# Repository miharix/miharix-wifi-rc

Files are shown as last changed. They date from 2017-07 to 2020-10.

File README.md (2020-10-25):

# Miharix WiFi RC
[SLO](#slo) / [DE](#de) / [ENG](#eng)

PCB and Firmware for **super cheap RC control over WiFi (Smart phone, Tablet, PC, ...)**

 I was a teacher(10 years) and wanted to make RC more affordable and be able to build something RC in class
 (yes all kids in a regular class and for grade - budget: 15€/kid)

So I made a this simple and very cheap module that enables to control standard RC components using WiFi and Phone/Tablet/PC
BUT the main difference to existing one is,
**IT DOESN'T NEED a special software**, only a web-browser and it **DOESN'T need an internet connection**.
*(you don't want to install something to 100 kids phones, and not all phones are the same! paid data traffic no go!)
And to reprogram it(new sw version / first steps to robotics) you need an inexpensive WittyCloud(~2€).*

The module was used in my class, 3 other teachers, and in 2 modellmaking summer camps. Totally around 300 kids*

Published in [elektor Elektor magazine11/2018](https://www.elektormagazine.com/index.php/magazine/elektor-52/42095)  on page 82

Published in magazine [TIM 4/2018](https://plus.si.cobiss.net/opac7/bib/40185093)  on page 24-27

 

* ***I stil have some asembled & programmed modules and also bare PCB-s left.
If you are interested, let me know [m.....x@gmail.com](https://mailhide.io/e/yFDyB)***

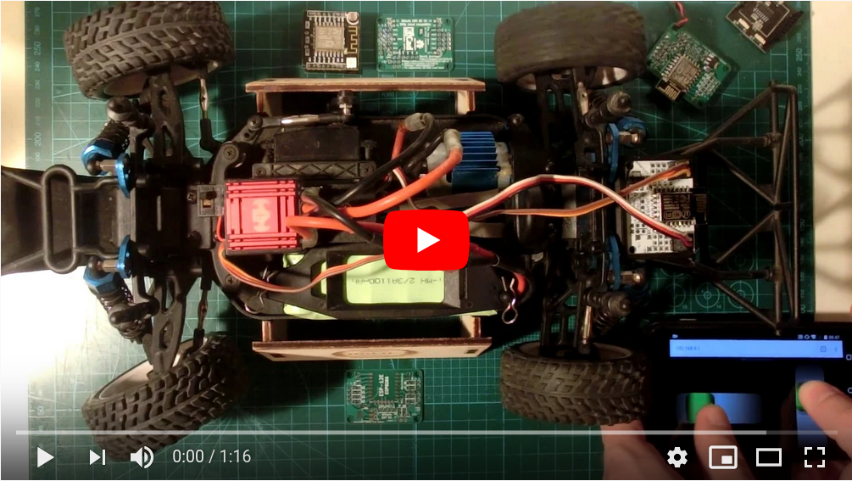
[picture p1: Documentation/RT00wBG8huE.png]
(https://www.youtube.com/watch?v=RT00wBG8huE)


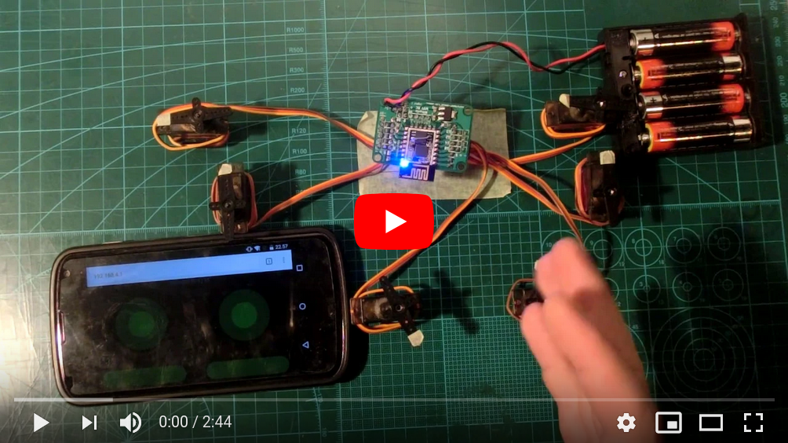
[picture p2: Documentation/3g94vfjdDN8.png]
(https://www.youtube.com/watch?v=3g94vfjdDN8)


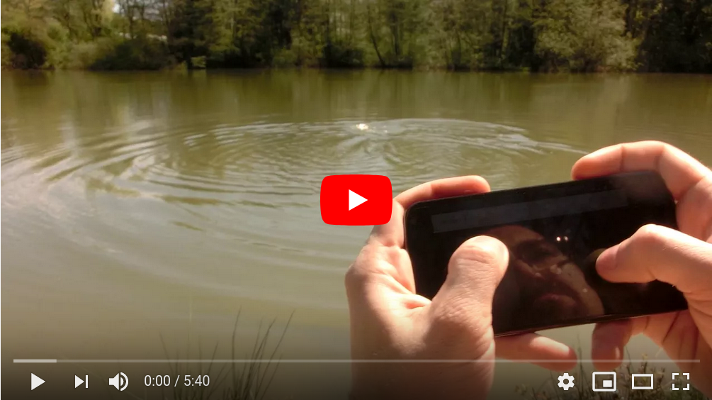
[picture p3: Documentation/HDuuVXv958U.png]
(https://www.youtube.com/watch?v=HDuuVXv958U)


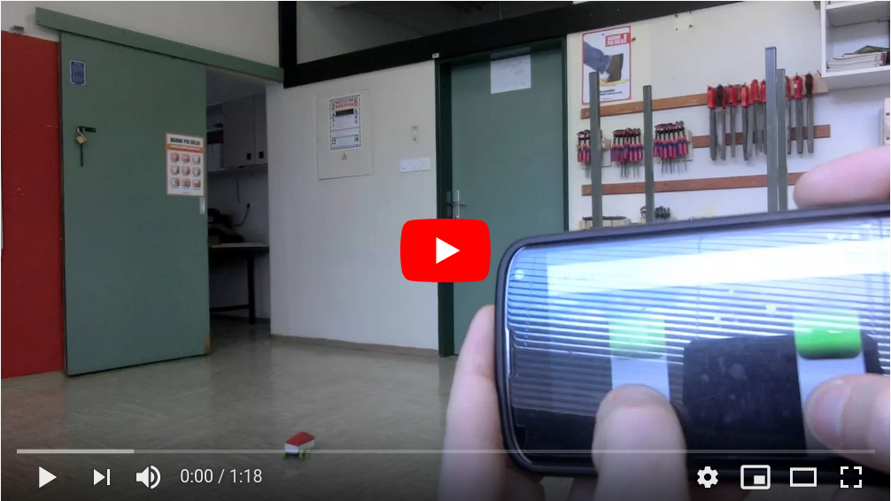
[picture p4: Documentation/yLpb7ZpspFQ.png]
(https://www.youtube.com/watch?v=yLpb7ZpspFQ)


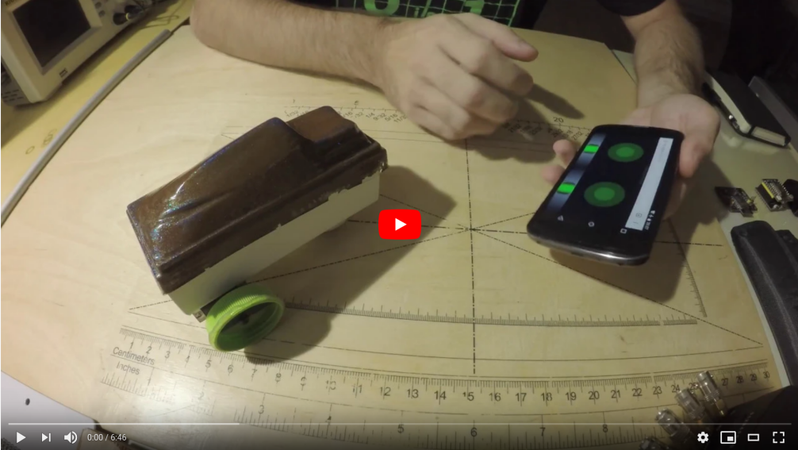
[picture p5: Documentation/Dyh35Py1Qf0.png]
(https://www.youtube.com/watch?v=Dyh35Py1Qf0)


---

#### [ENG]

PCB and Example Software for making super cheap RC control over WiFi (mobile phone,tablet,...)

If you like this project, you are welcome to support this and my further projects over https://paypal.me/miharix

What is in the folders:

* **3Dp** - simple 3Dp case
* **Arduino** - *source code examples for programming the module*
* **DIY** - *pdf for making PCB DIY at home*
* **Documentation** - *shematic and dimensions*
* **Gerber** - *files for a PCB factory*
* **Render** - *3D render of PCB*
* **Python** - *source code examples for PC control*

**For building you also need:**

* 1x ESP-12E *(ESP8266)*
* 1x MCP1755ST-3302E 3,3V 300mA
* 2x 10K SMD805 (10 kilo ohm)
* 2x 1µF SMD805 (1 mikro Farad)
* optional 3-44 pin header male one line breakable raster 2,54mm

For easy programming use "Witty cloud"

Ground range test cca 90m
[(5s before car stops, the signal is lost)](https://youtu.be/WoqIe_oOWTM)

Todo List:

* Testing on more devices
* Range test using external antena, router...
* Manual(video?) how to build, programming, configure...
* ~~(6 servo demo)Expo~~
* (6 servo demo)Disable nipple retun to center for individual axes 
* (6 servo demo)Simultan button(channel 5&6) press and nipple usage
* ...

---

#### [DE]

Schaltung und  Programmierbeispiele um eine super-billige Modellbaufernbedienung über WiFi (Smartphone, Tablett,...) zu bauen.

Wen ihnen die Schaltung nutzbar ist, können Sie die Weiterentwicklung diesen und zukünftige Projekte mit kleiner Donation über https://paypal.me/miharix unterstützen.

Was sich in der Unterordner befindet:

* **3Dp** - einfaches 3Dp Gehäuse
* **Arduino** - *Programmierbeispiele um den Modul zu programmieren*
* **DIY** - *pdf um die Schaltung Zuhause selber nachzumachen*
* **Documentation** - *Schema der Schaltung und Maßnahmen*
* **Gerber** - *Dateien für PCB Hersteller*
* **Render** - *3D Rander von PCB*
* **Python** - *Programmierbeispiele um Mudil mit PC zu steuern*

**Um es zu bauen braucht man noch:**

* 1x ESP-12E *(ESP8266)*
* 1x MCP1755ST-3302E 3,3V 300mA
* 2x 10K SMD805 (10 kilo ohm)
* 2x 1µF SMD805 (1 mikro Farad)
* Optional 3-44 Stiftleisten Raster 2,54mm

Um es es ganz einfach zu Programmieren ist die "Witty cloud" als Programmierer gerät vorgesehen. 

Getestete Reichweite am Boden hohe cca 80m
 [(5s bevor der Auto anhielt wurde der Signal abgebrochen)](https://youtu.be/WoqIe_oOWTM)

Noch zu tun:

* Test auf Kompatibilität mit noch mehreren Geraten
* Test der Reichweite bei Gebrauch einer externer Antenne, Routers...
* Anleitung(Video?) wie man es baut, programmiert, konfiguriert...
* ~~(6 servo demo)Expo~~
* (6 servo demo)Ausschalten in die Mitte zurück springen beliebiges Knüppel  
* (6 servo demo)Gleichzeitige Aktivierung der Knöpfe 5&6 und Knüppel Bewegung.
* ...

---

#### [SLO]

Vezje in programski primeri za izdelavo super poceni RV preko WiFi (pametni telefon,tablica,...)

V kolikor vam vezje koristi, lahko podprete razvoj tega ter bodočih projektov s donacijo preko: https://paypal.me/miharix

Kaj se nahaja v mapah:

* **3Dp** - preprosto ohišje za 3Dp
* **Arduino** - *programski primeri za programiranje modula*
* **DIY** - *pdf za izdelavo tiskanega vezja v domači delavnici*
* **Documentation** - *shema vezave in mere*
* **Gerber** - *datoteke za proizvajalca vezij*
* **Render** - *3D izris vezja*
* **Python** - *primer kode za krmiljenje iz računalnika*

**Za  izdelavo še potrebujete:**

* 1x ESP-12E *(ESP8266)*
* 1x MCP1755ST-3302E 3,3V 300mA
* 2x 10K SMD805 (10 kilo ohm)
* 2x 1µF SMD805 (1 mikro Farad)
* opcijsko 3-44 letev moška enoredna lomljiva raster 2,54mm

Za preprosto programiranje predvidena uporaba "Witty cloud"

Testiran domet na zemlji približno 80m
 [(5s preden se avto ustavi na tem posnetku, se je zgubil signal)](https://youtu.be/WoqIe_oOWTM)

Za naredit:

* Testirat na čim več napravah
* Test dometa pri uporabi zunanje antene, ruterja...
* Navodila(video?) kako izdelat, programirat, nastavljat...
* ~~(6 servo demo)Expo~~
* (6 servo demo)Izklop samodejnega povratka ročice poljubne osi v središče
* (6 servo demo)Sočasno aktivianje gumba za 5&6 med premikanjem ročic
* ...

---

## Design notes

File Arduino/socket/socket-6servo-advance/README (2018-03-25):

* 6 servo support
* easy configurable
	* each servo configurable:
		*	Trim center
		*	Max position
		*	Min position
		*	Fail position
		*	Expo rate
		*	Rate speed
		*	Reverse
	* Fail save timeout
	* 9 different control designs
	* RC model name
	* Access Point(AP) mode or connect to existing WiFi
	* SSID
	* Password
* includes possibility to hard reset to "factory" settings
* in case of wrong SSID or Password in non AP mode after 5 min triggers reset to "factory" settings
* "factory" settings SSID includes MAC

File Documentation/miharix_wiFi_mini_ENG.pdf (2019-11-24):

# Miharix WiFi RC

# Control your RC models over WiFi (e.g.: smartphone, tablet, laptop...) Without a need for a special App Without a need for Internet or Mobile data

# WiFi Antenna

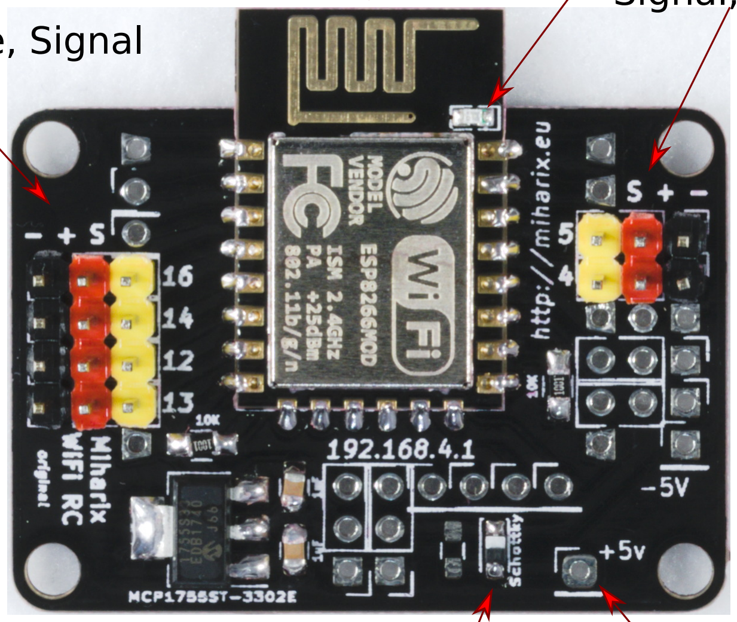
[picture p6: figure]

## Servo 1 Servo 3 Servo 5 Servo 6

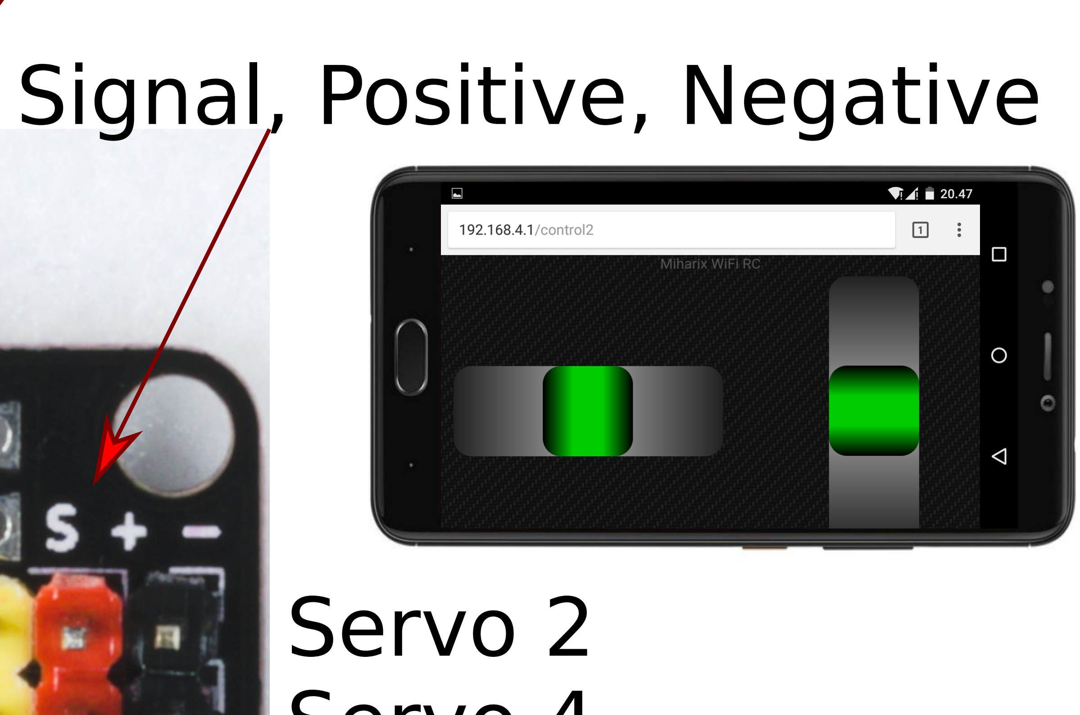
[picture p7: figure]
Servo 2; Signal, Positive, Negative

## Servo 4

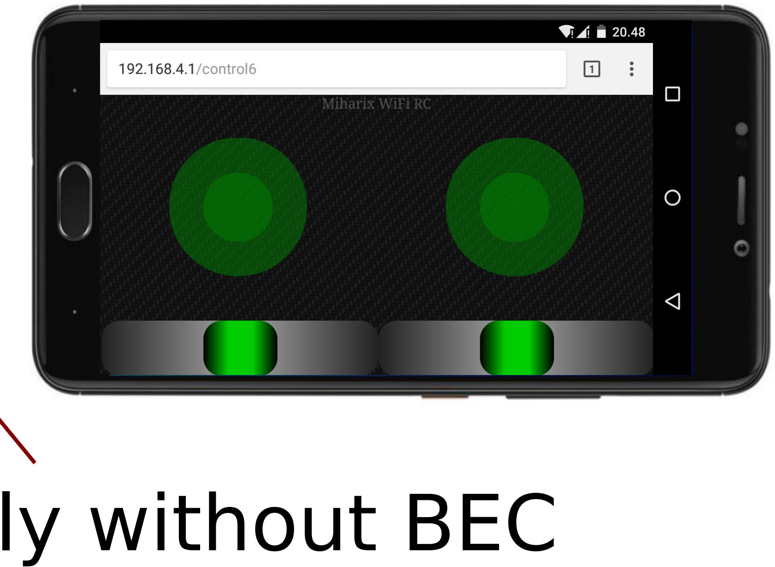
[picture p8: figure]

## Optional: Power supply without BEC

Voltage should not exceed max servo voltage for used servo motors

## Most of the time 5V (4xAA)

Wrong polarity protection for optional power supply

## Negative, Positive, Signal

Usage in short:
1. Turn on power supply for module
2. On mobile device (e.g. smartphone) turn on WiFi

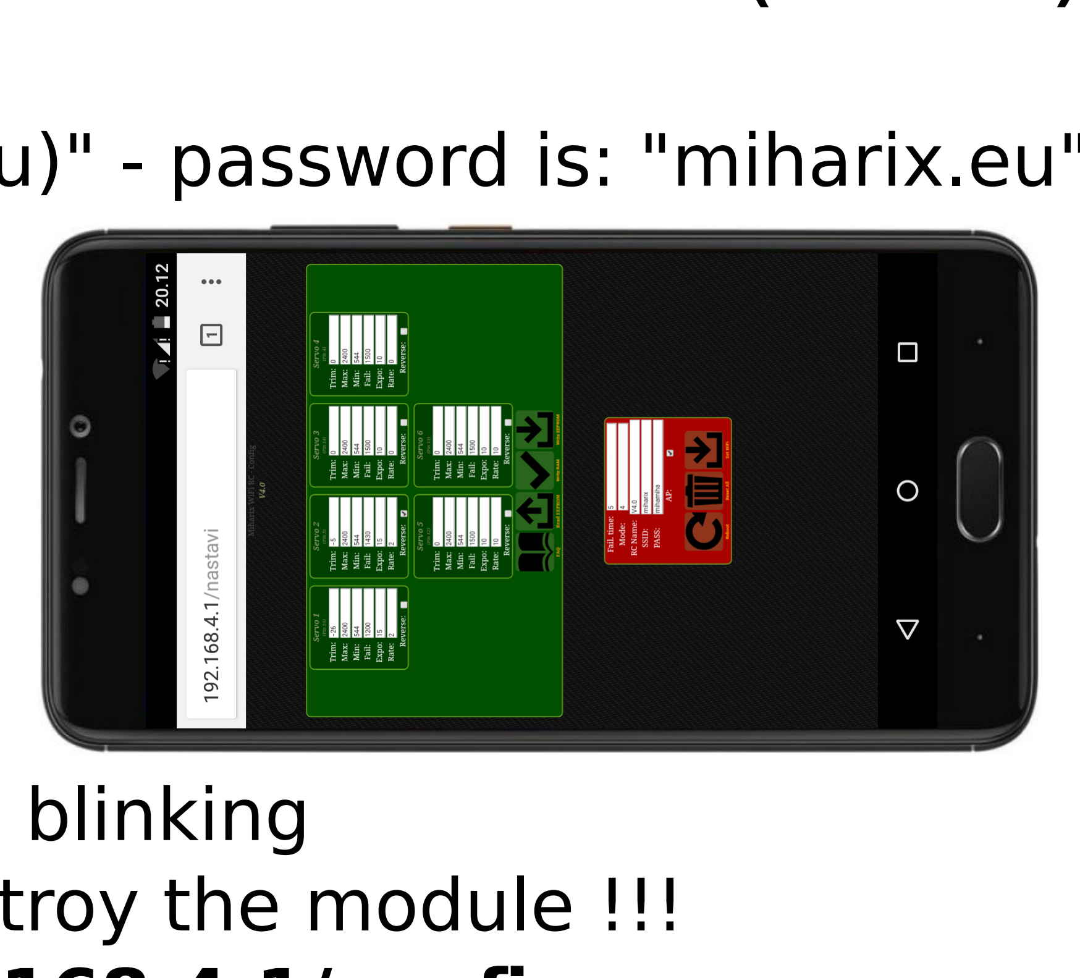
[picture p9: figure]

3. Connect to WiFi, who's names is made of modules MAC and ends on "(miharix.eu)" - password is: "miharix.eu"
4. Open your browser, the best if it's Chrome
5. In URL row type web address "http://192.168.4.1"
6. Follow manual on the website

FAQ:
I forgot my password - Find on the back side marked GPIO0 (under Servo4)
You need to short the left signal GPIO0 and right outer - (minus) till the LED stops blinking
WARNING do not short any of inner(yellow/signal) whit middle(red) pin, it will destroy the module !!! I have set up the module but I would like to change settings: http://192.168.4.1/config
(also possible /nastavi /uredi, /administrator, /admin, /setup, /root)
Do I now have Internet wherever I am? :-) No, WiFi doesn't automatically mean internet
Do I need internet for controlling my model? No, only a device, that supports WiFi and has a browser Can I connect model to existing WiFi? Yes, in settings disable AP and insert networks SSID and password I typed wrong password for existing WiFi. Leave on for 5min, module will factory reset automatically. What's maximum range? Tested cca. 80-90m (90-100 Yard)
What is that "Mode:" ? Module ha multiple interfaces for controlling.
You can try them fast on http://192.168.4.1/control1 (next is control2, control3 ...)

LED - status indicator states:
On - fail-save
Off - connection is active
Progressive faster blinking for 1min - Sure to do a factory reset?

For Each Servo you can set
Reverse, Trim, Max, Min, Fail-save, Expo, Rate

Able to set custom WiFi name and password

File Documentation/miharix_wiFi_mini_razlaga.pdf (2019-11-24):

# Miharix WiFi RC

# Krmiljenje modelarskih modelov preko WiFi (npr: telefon, tablica, prenosnik...) Brez potrebe po namenski aplikaciji Brez potrebe po Internetu ali Mobilnih podatkih

# WiFi Antena

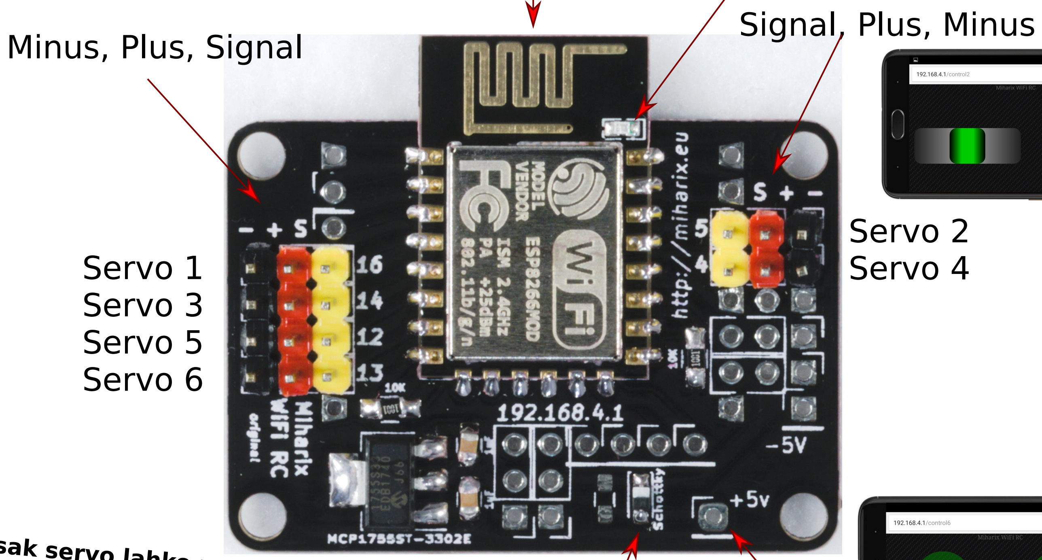
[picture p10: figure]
Signal, Plus, Minus Minus, Plus, Signal

## Servo 1 Servo 3 Servo 5 Servo 6

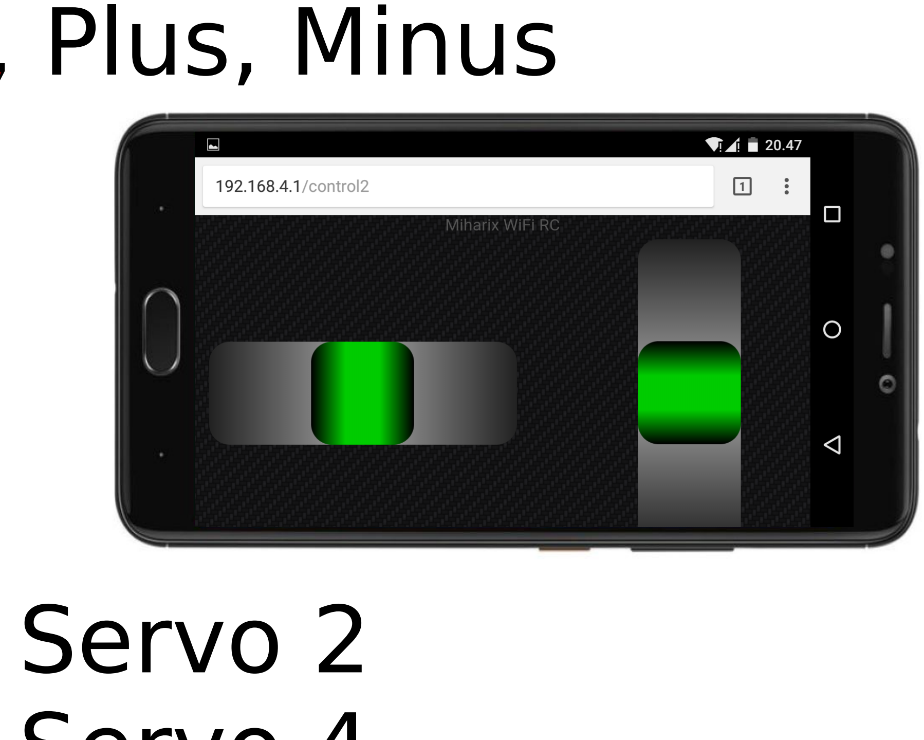
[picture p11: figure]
Servo 2

## Servo 4

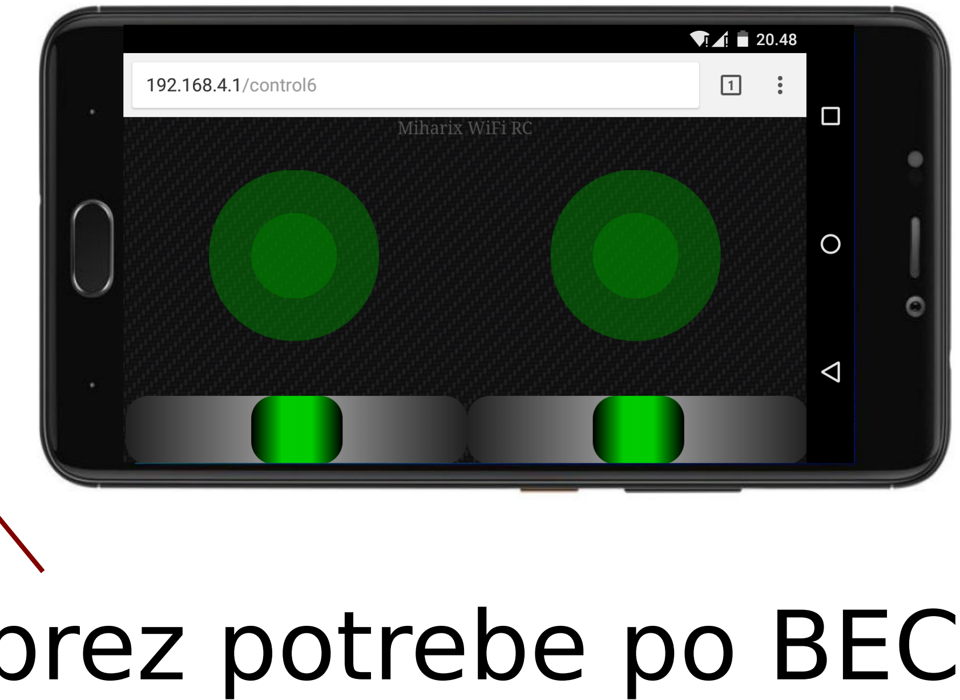
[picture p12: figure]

## Opcijsko: Napajanje brez potrebe po BEC

Napetost ne sme preseči maksimalne napajalne napetosti uporalbjenih servo motorjev

## Najpogosteje 5V (4xAA)

Zaščita pred napačno polariteto opcijskega napajanja

Uporaba na kratko:
1. Vklopi napajanje modula
2. Na mobilni napravi(npr telefon) vklopi WiF

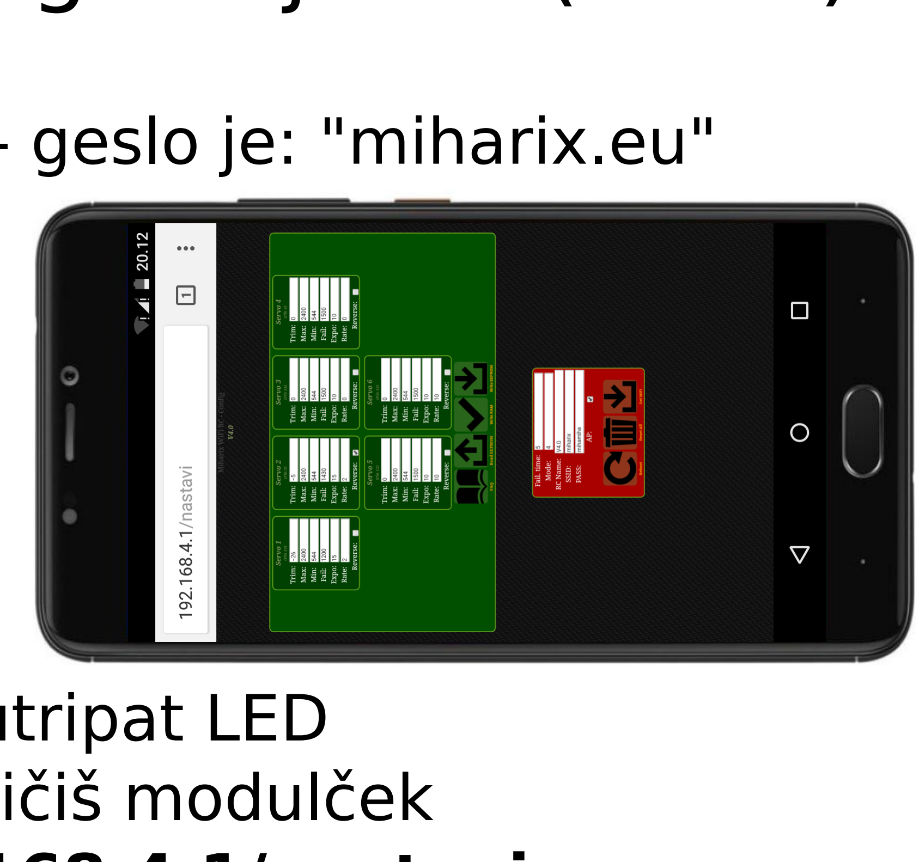
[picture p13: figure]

3. poveži se na WiFi, ki je sestavljen iz MAC modula ter se konča z "(miharix.eu)" - geslo je: "miharix.eu"
4. Odpri brskalnik, najbolje Chrome
5. V URL vrstico vtipkaj spletni naslov "http://192.168.4.1"
6. Sledi navodilom na spletni strani

FAQ:
Pozabil sem geslo - Poišči na zadnji strani označen GPIO0 (takoj pod Servo4)
Skleniti moraš skrajno notranji GPIO0 ter zunanji desni - (minus) dokler ne neha utripat LED POZOR ne smeš sklenit nobenega rumenega(notranji) z rdečim(sredina), sicer uničiš modulček Nastavil sem modul in bi rad naknadno spremnil nastavitve: http://192.168.4.1/nastavi (lahko tudi /uredi, /administrator, /admin, /config, /setup, /root)
A imam sedaj Internet kjer koli sem? :-) Ne, WiFi ne pomeni avtomatično internet
Rabim internet za upravljanje modela? Ne, le napravo ki podpira WiFi ter ima brskalnik
Lahko priključim model na obstoječi WiFi? Da, onemogoči v nastavitvah AP, vnesi SSID in geslo omrežja Vtipkal sem napačsno geslo za obstoječi WiFi. Pusti prižgano 5min, modul se bo ponastavil sam Kakšen je domet? Testirano cca 80-90m
Kaj je to "Mode:" ? Vmesnik ima več oblik za krmiljenje.
Na hitro jih lahko preizkusiš z http://192.168.4.1/control1 (naslednji je control2, control3 ...)

LED - indikator stanja
Prižgan - failsave
Izklopljen - povezava aktivna
Vedno hitrejše utripanje 1min - Res želiš vse resetirat?

Za vsak servo lahko nastaviš: Reverse, Trim, Max, Min, Failsave, Expo, Rate

Nastavljivo poljubno WiFi ime ter geslo

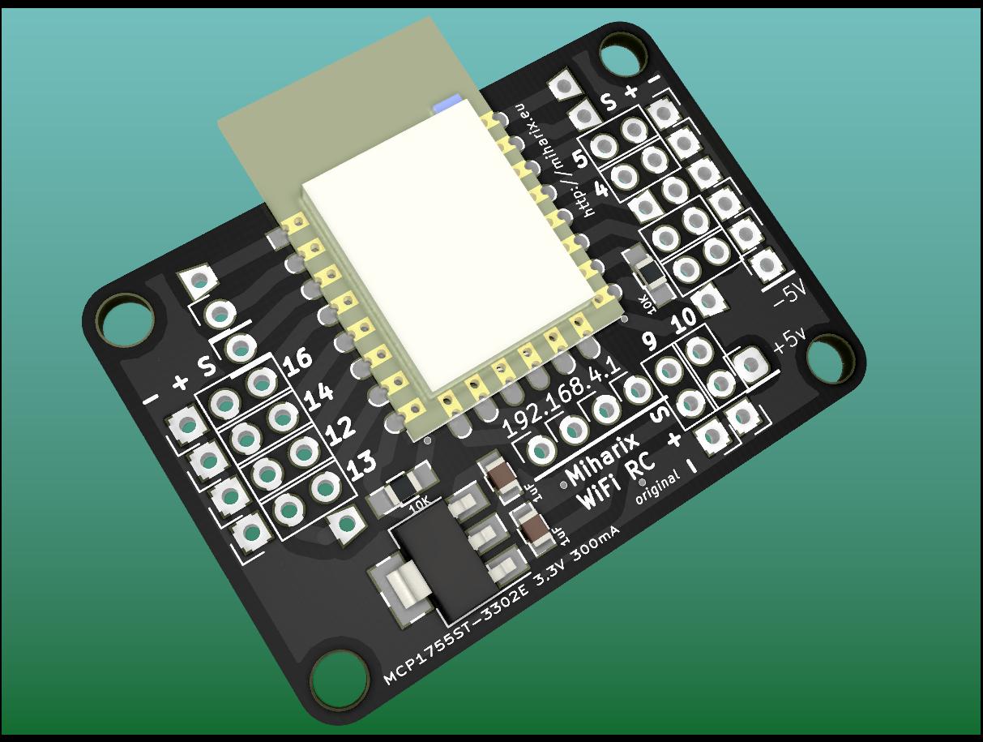
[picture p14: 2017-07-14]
Render/V3/ESP_servo_v3_2.jpg

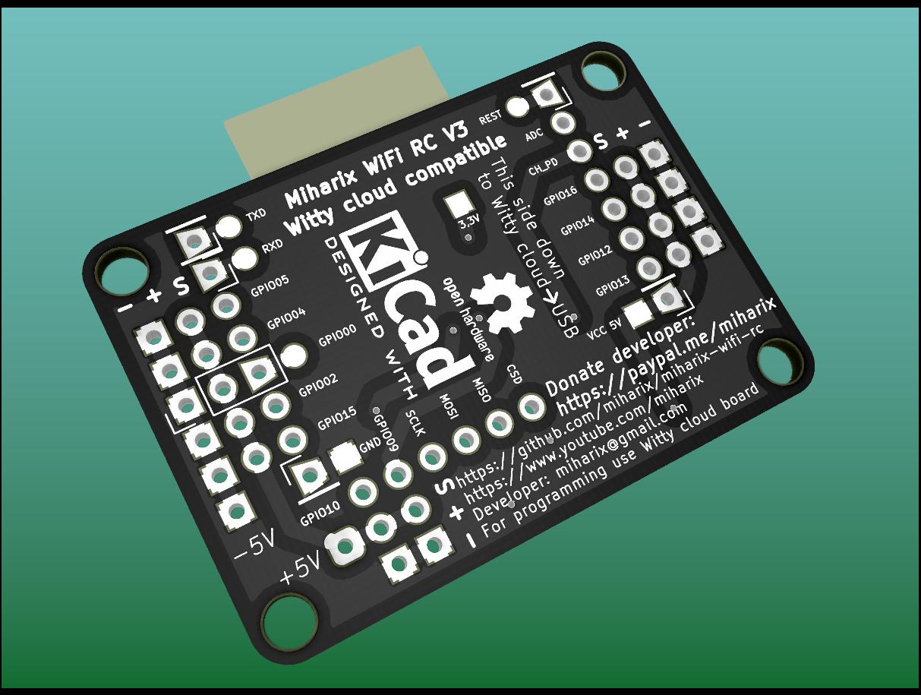
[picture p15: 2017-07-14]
Render/V3/ESP_servo_v3_5.jpg

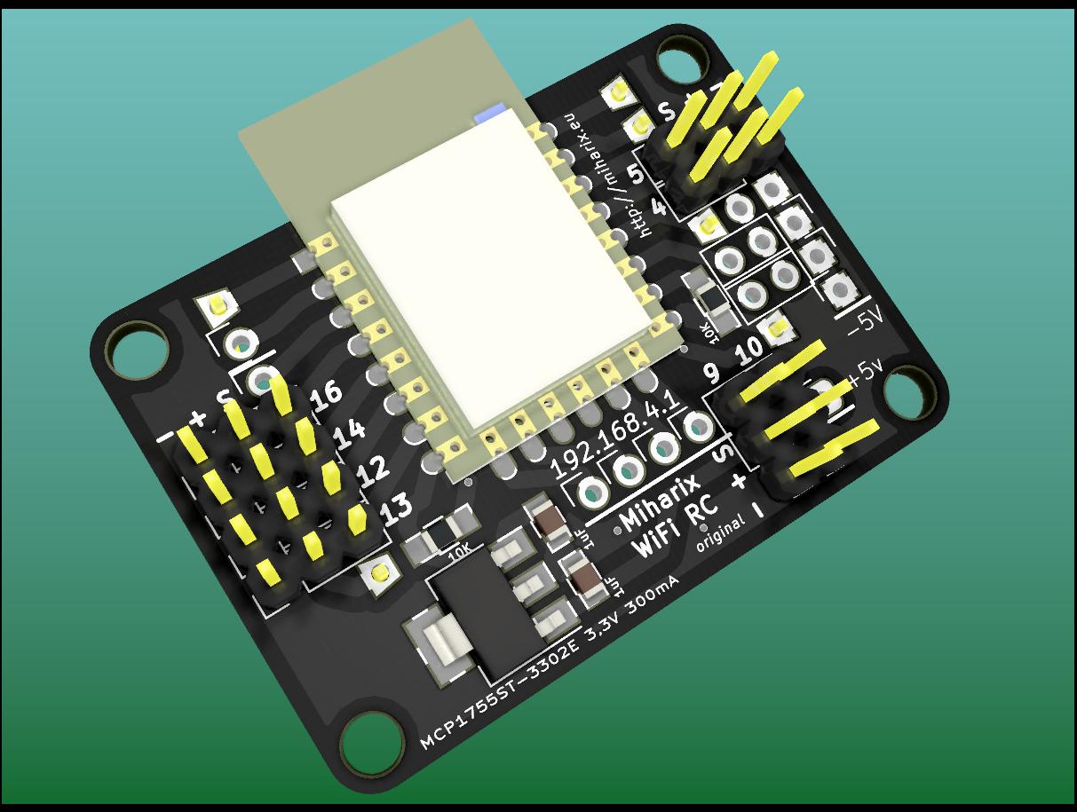
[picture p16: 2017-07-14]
Render/V3/ESP_servo_v3.jpg

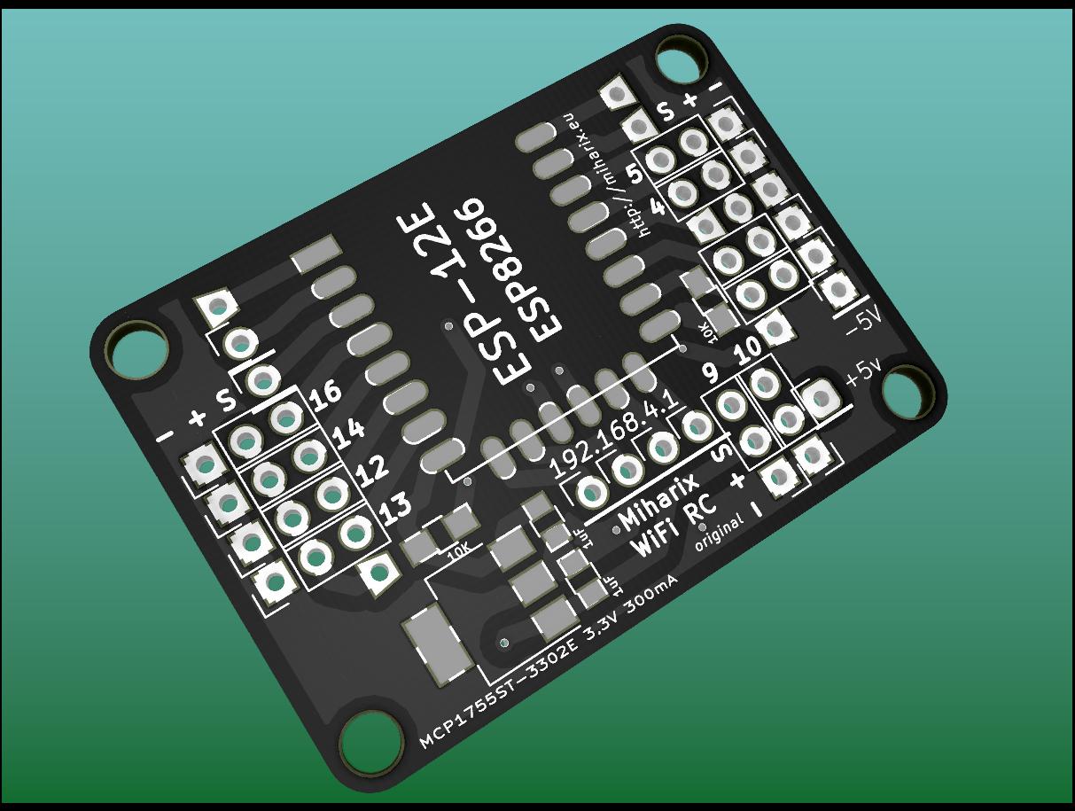
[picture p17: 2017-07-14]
Render/V3/ESP_servo_v3_3.jpg

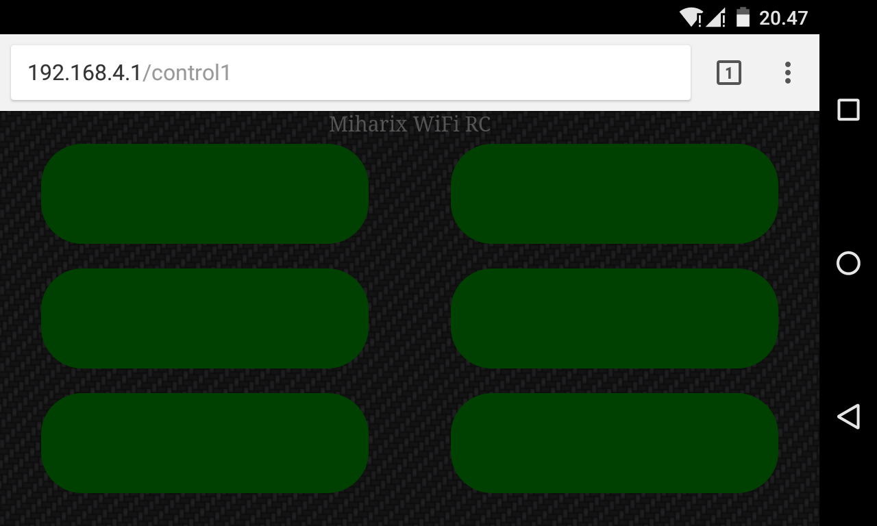
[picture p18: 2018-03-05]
Arduino/socket/socket-6servo-advance/Screenshots/Screenshot_nexus4_CONTROL1.png

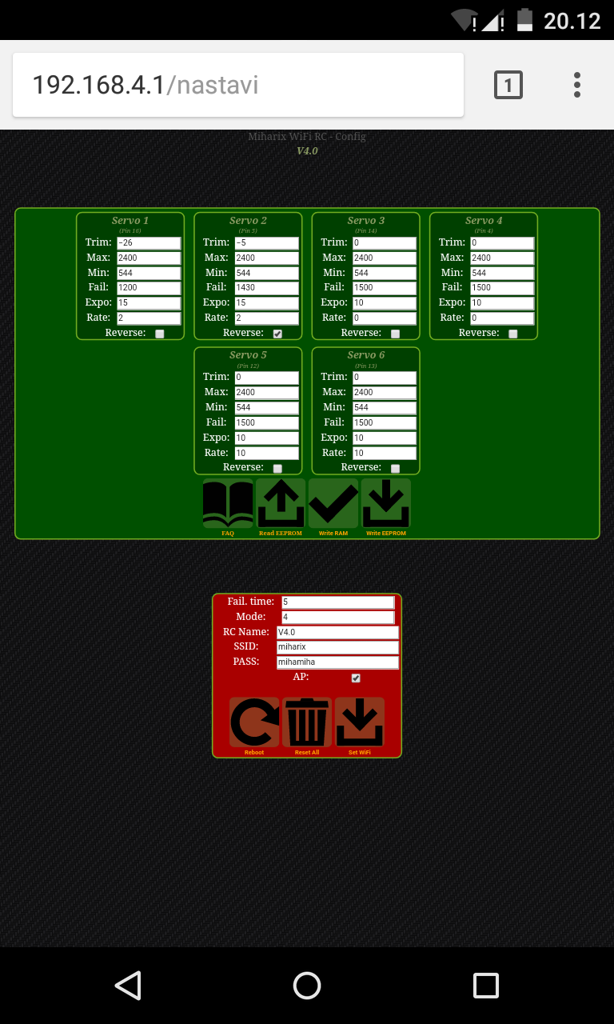
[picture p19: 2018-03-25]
Arduino/socket/socket-6servo-advance/Screenshots/Screenshot_nexus4_CONFIG.png

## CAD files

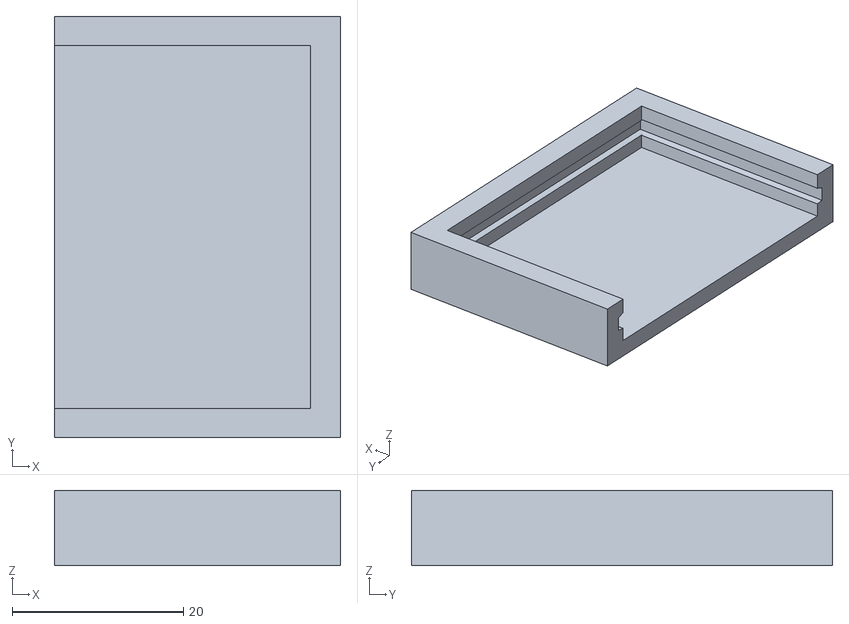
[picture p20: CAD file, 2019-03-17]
3Dp/pcb_protect_v3.stl
33.4 x 49.1 x 8.80

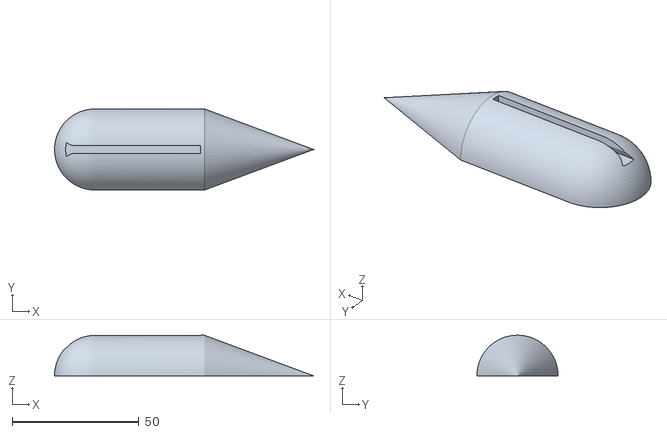
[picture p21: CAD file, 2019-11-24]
model_examples/Sumpi/sumpi.stl
102.0 x 32.0 x 16.0

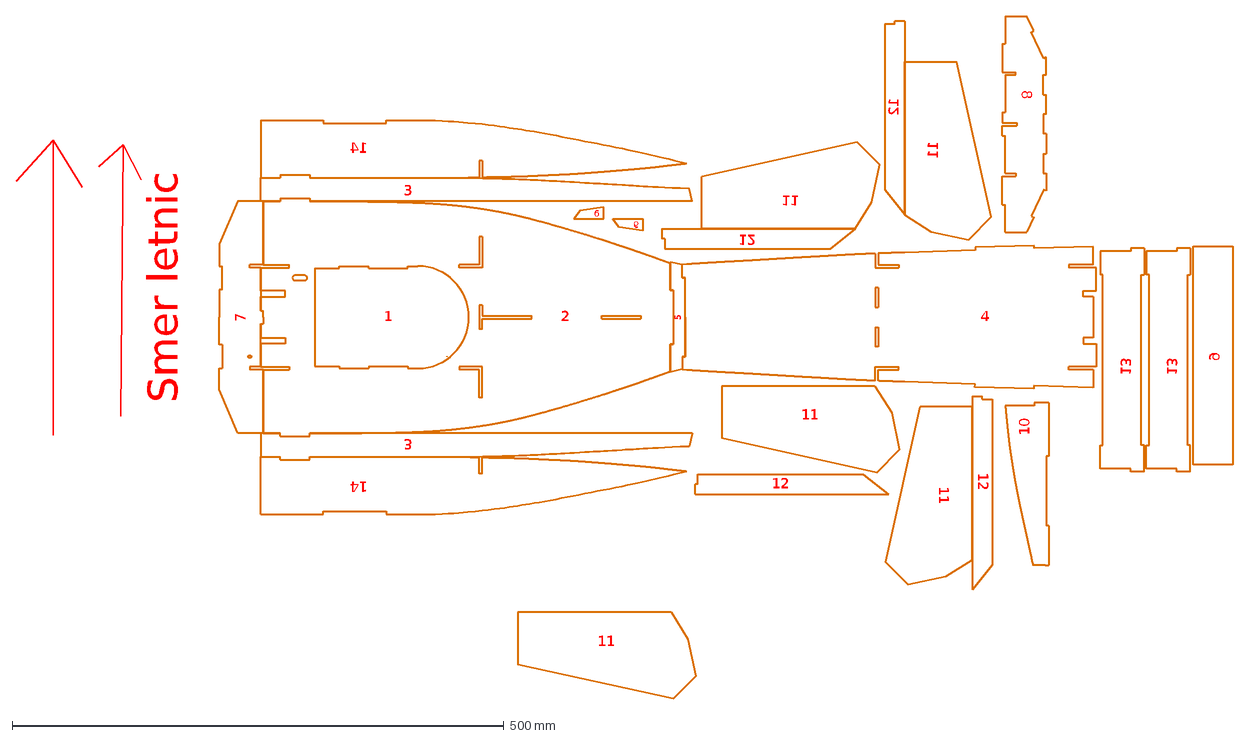
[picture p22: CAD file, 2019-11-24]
model_examples/Sumpi/sumpi_3mm.dxf
6
1
2
7
5
11
3
14
4
12
13
9
Smer letnic
8
10

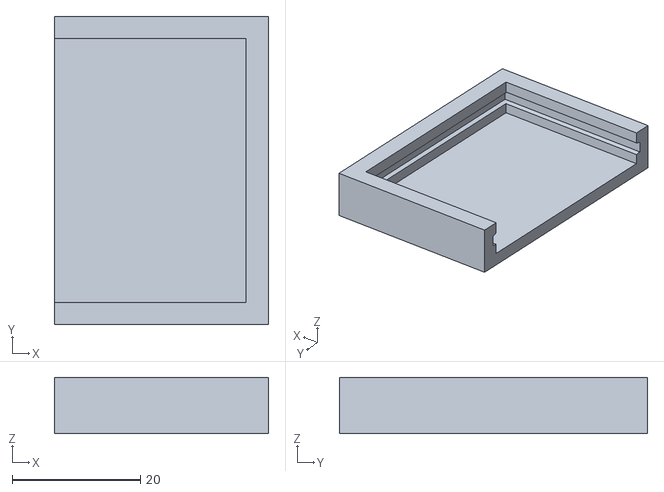
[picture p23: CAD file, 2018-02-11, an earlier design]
3Dp/pcb_protect.stl
33.4 x 48.0 x 8.80

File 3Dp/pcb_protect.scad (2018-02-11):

pcb_height=31;
pcb_width=43.18;
pcb_thick=2;
grove=1;
walls=2.4;
bottom_offset=2;
chamfer_top=0.7;//[0.0:1.0]
chamfer_bottom=0.3;//[0.0:1.0]


difference(){
//box
translate([walls/2+0.1,0,pcb_thick/2+bottom_offset/2]){
cube([pcb_height+walls,pcb_width+walls*2,pcb_thick+walls*2+bottom_offset],center=true);
}

//pcb
color("green")
translate([0,0,pcb_thick/2+bottom_offset]){
cube([pcb_height,pcb_width,pcb_thick],center=true);
}

//grove
color("blue")
translate([-grove/2,0,pcb_thick+walls/2+bottom_offset]){
cube([pcb_height-grove,pcb_width-grove*2,walls+0.01],center=true);
}


//chamfer top
color("red")
translate([-grove/2,0,pcb_thick+walls/2+bottom_offset-0.01]){
linear_extrude(height = walls+0.1, center = true, convexity = 3, scale = chamfer_top){
square(size = [pcb_height, pcb_width], center = true);
}
}

//bottom offset
color("Gray")
translate([-grove/2,0,bottom_offset/2]){
cube([pcb_height-grove,pcb_width-grove*2,bottom_offset+0.01],center=true);
}

//chamfer bottom
color("Purple")
translate([-grove/2,0,bottom_offset/2+0.01]){
mirror([0,0,1]) 
linear_extrude(height = bottom_offset, center = true, convexity = 3, scale = chamfer_bottom){
square(size = [pcb_height, pcb_width], center = true);
}
}

}

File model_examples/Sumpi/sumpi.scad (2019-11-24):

$fn=80;

module trikotnik(stranica,visina){
    polmer=(stranica*sqrt(3))/3;
    translate([visina/2,0,polmer/2])
    rotate([0,-90,0])
    cylinder(h=visina,r=polmer,$fn=3);
}



difference(){

hull(){

/*translate([0,0,0])
rotate([0,90,0])
cylinder(h=43,r=16,center=true);
*/
translate([43,0,0])
rotate([0,90,0])
cylinder(h=43, r1=16, r2=0,center=true);

translate([-43/2,0,0])
sphere(r=16);
}

translate([-10,0,11])
trikotnik(5.5,60);

translate([-10,0,16])
cube([60,3,6],center=true);

translate([10,0,-16])
cube([130,16*2,16*2],center=true);
}

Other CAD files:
model_examples/MobiRobi/nacrt.dxf
model_examples/Sumpi/sumpi.dxf

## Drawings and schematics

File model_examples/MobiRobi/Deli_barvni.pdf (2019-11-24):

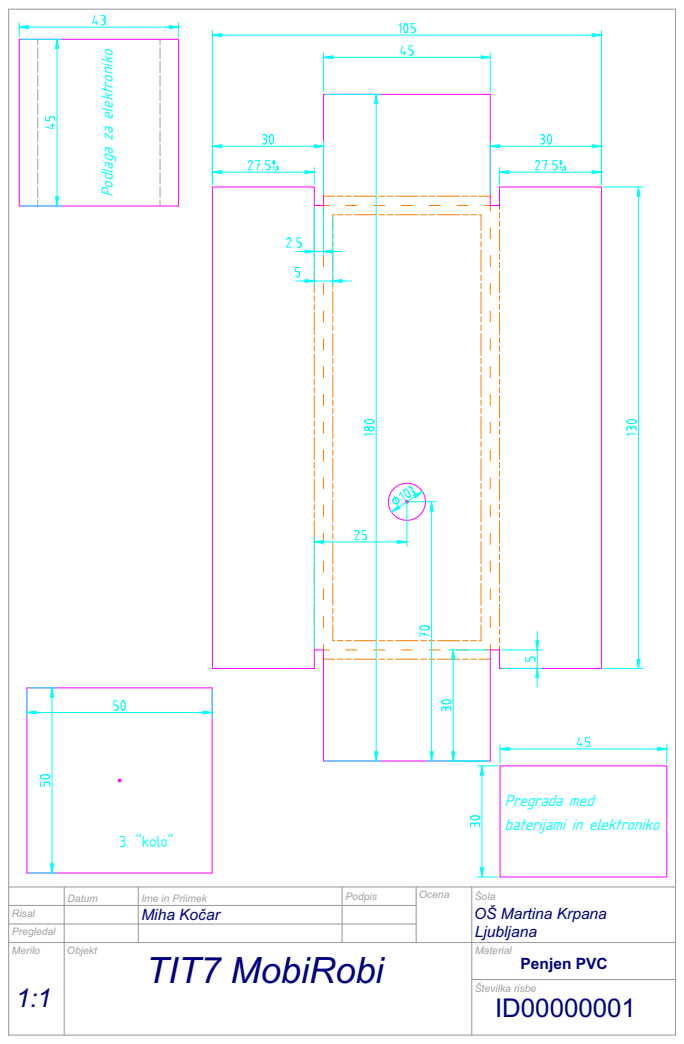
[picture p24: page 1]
Številka risbe ID00000001; Podlaga; elektroniko; 3. "kolo"

Pregrada med
baterijami in elektroniko

Datum | Ime in Priimek | Podpis | Ocena Miha Kočar | OŠ Martina Krpana Šola Material Ljubljana

Risal
Pregledal
Merilo 1:1 | Objekt TIT7 MobiRobi | Penjen PVC

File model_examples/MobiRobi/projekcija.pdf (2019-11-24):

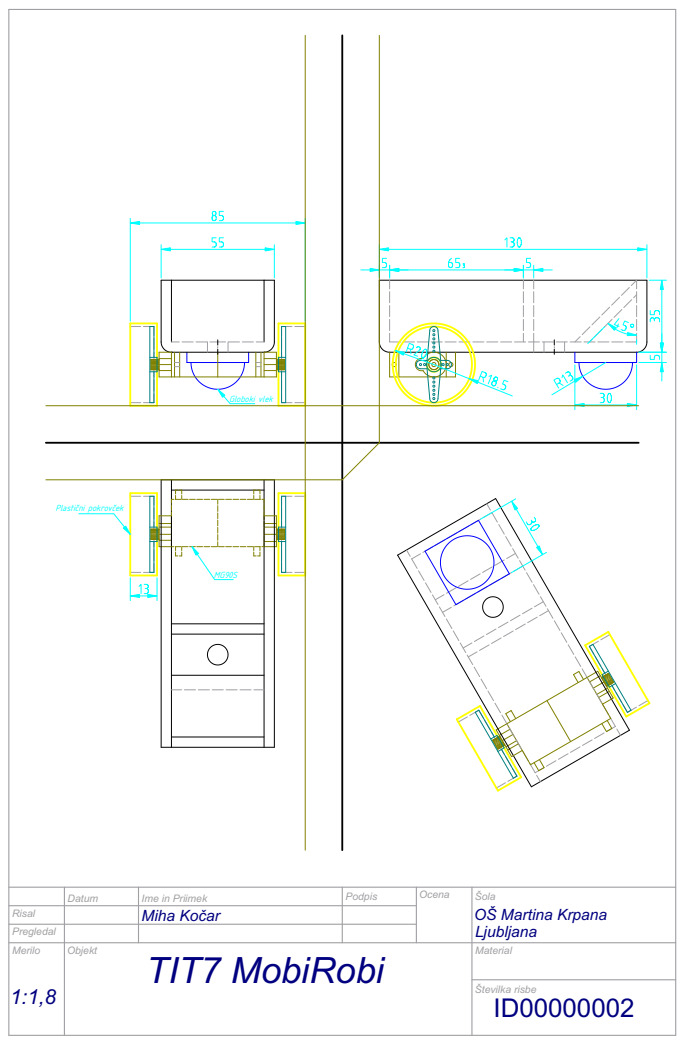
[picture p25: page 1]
Številka risbe ID00000002; Plastični pokrovček; Globoki vlek

Datum | Ime in Priimek | Podpis | Ocena Miha Kočar | OŠ Martina Krpana Šola Material Ljubljana

Risal
Pregledal
Merilo 1:1,8 | Objekt TIT7 MobiRobi

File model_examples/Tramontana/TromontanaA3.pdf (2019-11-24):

7
7

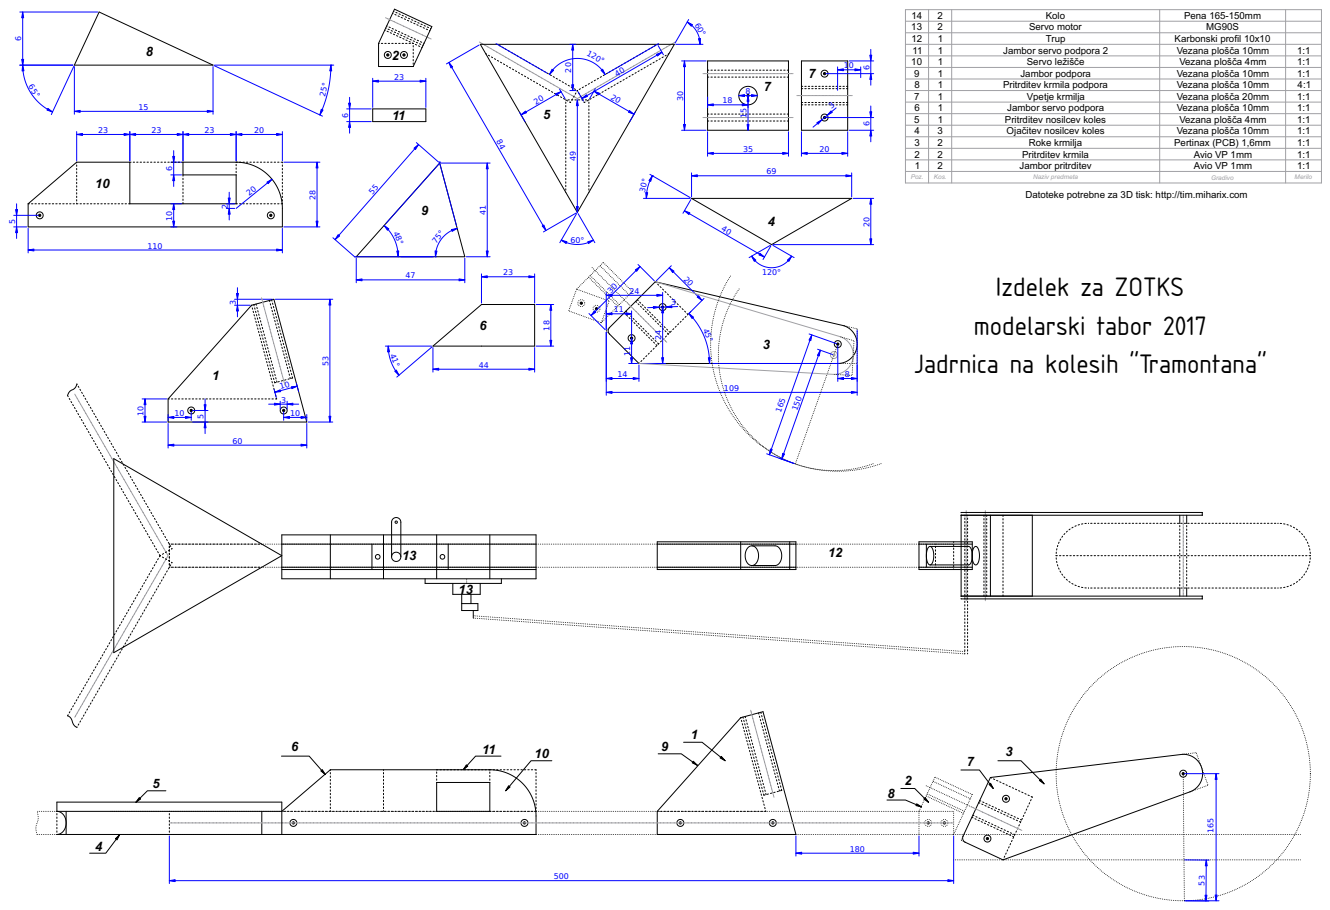
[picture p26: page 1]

14 | 2 | Kolo | Pena 165-150mm
13 | 2 | Servo motor | MG90S
12 | 1 | Trup | Karbonski profil 10x10
11 | 1 | Jambor servo podpora 2 | Vezana plošča 10mm | 1:1
10 | 1 | Servo ležišče | Vezana plošča 4mm | 1:1
9 | 1 | Jambor podpora | Vezana plošča 10mm | 1:1
8 | 1 | Pritrditev krmila podpora | Vezana plošča 10mm | 4:1
7 | 1 | Vpetje krmilja | Vezana plošča 20mm | 1:1
6 | 1 | Jambor servo podpora | Vezana plošča 10mm | 1:1
5 | 1 | Pritrditev nosilcev koles | Vezana plošča 4mm | 1:1
4 | 3 | Ojačitev nosilcev koles | Vezana plošča 10mm | 1:1
3 | 2 | Roke krmilja | Pertinax (PCB) 1,6mm | 1:1
2 | 2 | Pritrditev krmila | Avio VP 1mm | 1:1
1 | 2 | Jambor pritrditev | Avio VP 1mm | 1:1

Poz. | Kos. | Naziv predmeta | Gradivo | Merilo

Datoteke potrebne za 3D tisk: http://tim.miharix.com
Izdelek za ZOTKS
modelarski tabor 2017
Jadrnica na kolesih "Tramontana

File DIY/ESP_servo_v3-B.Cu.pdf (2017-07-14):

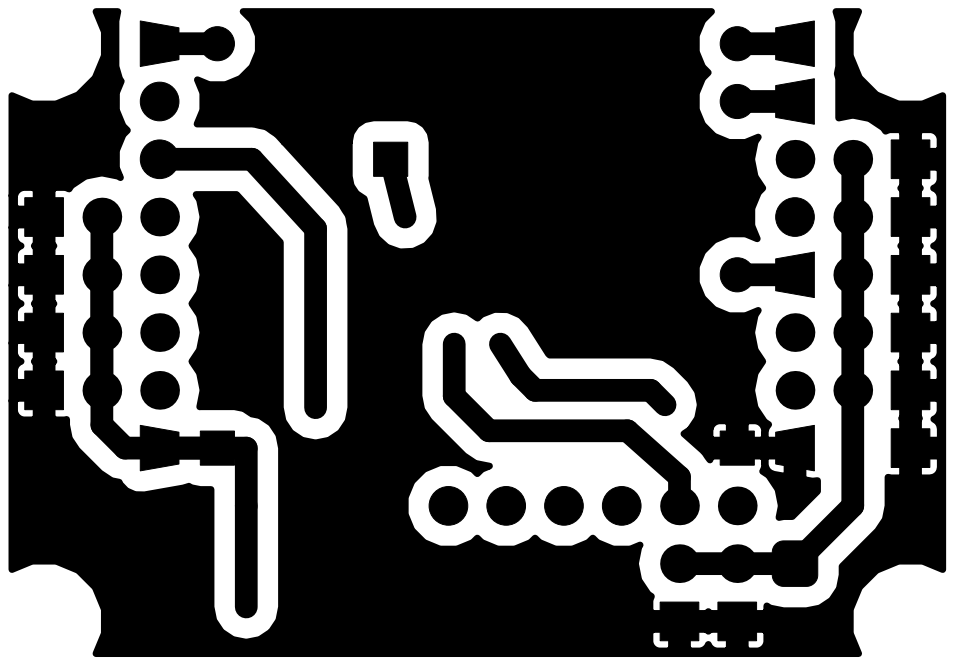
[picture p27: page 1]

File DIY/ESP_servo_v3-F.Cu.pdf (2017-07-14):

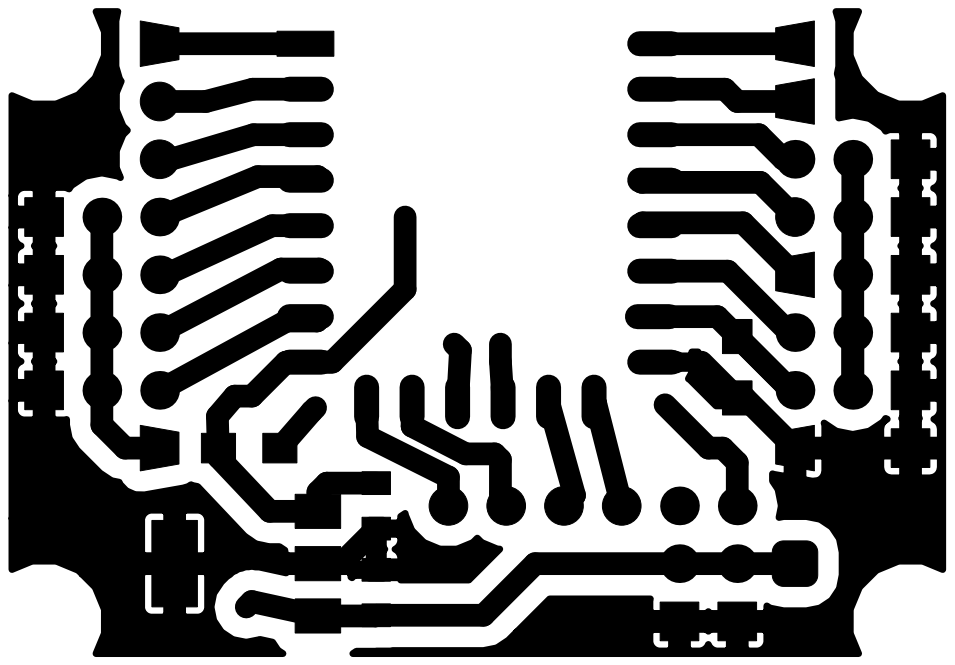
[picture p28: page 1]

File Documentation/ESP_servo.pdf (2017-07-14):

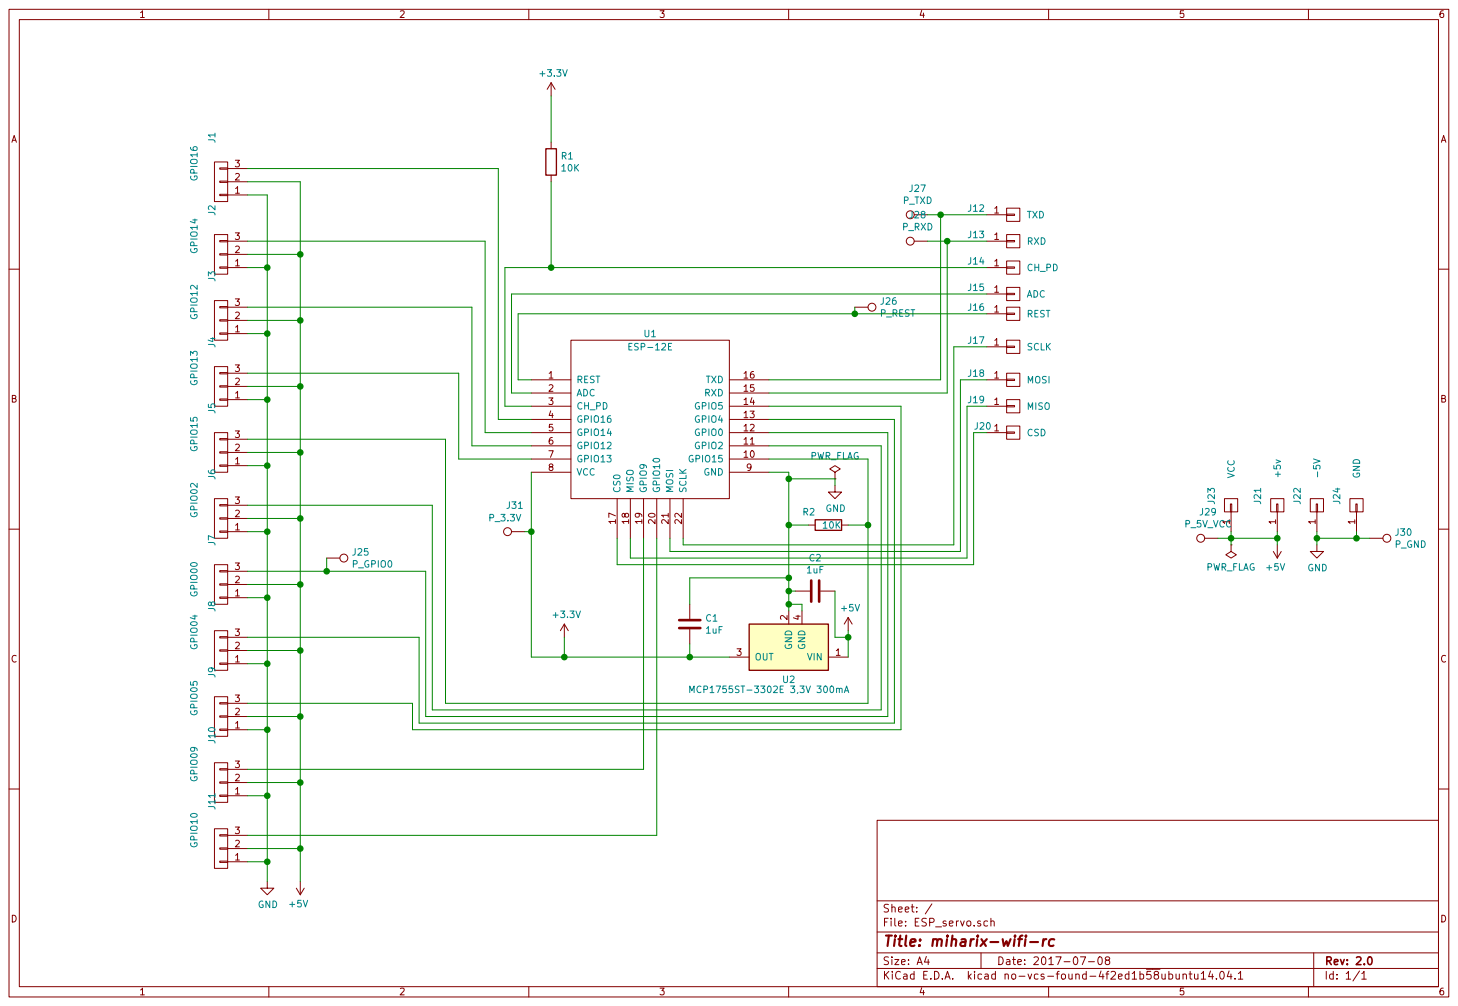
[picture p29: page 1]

File: ESP_servo.sch Sheet: /
Id: 1/1 Title: miharix-wifi-rc

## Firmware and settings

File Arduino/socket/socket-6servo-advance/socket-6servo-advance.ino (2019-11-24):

#include <ESP8266WiFi.h>
#include <WiFiClient.h>
//#include <ESP8266WiFiMulti.h> // za več wifijev
#include <ESP8266mDNS.h>
#include <ESP8266WebServer.h>
#include <WebSocketsServer.h>
#include <ArduinoJson.h> //for parsing/saving json file
#include <FS.h>   // Include the SPIFFS library
#include <Servo.h>


//#define DEBUG
//#define DEBUG1

#define PRINTLN(var) Serial.print(#var ": "); Serial.println(var)

//ESP8266WiFiMulti wifiMulti;     // Create an instance of the ESP8266WiFiMulti class, called 'wifiMulti'

ESP8266WebServer server(80);    // Create a webserver object that listens for HTTP request on port 80
WebSocketsServer webSocket = WebSocketsServer(81);    // create a websocket server on port 81

#define SERVO1   16
#define SERVO2   5
#define SERVO3   14
#define SERVO4   4
#define SERVO5   12
#define SERVO6   13


#define HARD_RESET_PIN 0

Servo servo1;
Servo servo2;
Servo servo3;
Servo servo4;
Servo servo5;
Servo servo6;

unsigned long previousMillis = 0;
unsigned long previousMillisR1 = 0;
unsigned long previousMillisR2 = 0;
unsigned long previousMillisR3 = 0;
unsigned long previousMillisR4 = 0;
unsigned long previousMillisR5 = 0;
unsigned long previousMillisR6 = 0;

const long interval = 1000; //interval for checking failsave state
bool S1_6_flag = false;
word SameStateCount = 0; //counter of non changed states - failsave
char S1_buff[3];//servo socket buffer
char S2_buff[3];
char S3_buff[3];
char S4_buff[3];
char S5_buff[3];
char S6_buff[3];

//int rate_interval = 0;

byte Servo1_target = 90;
byte Servo2_target = 90;
byte Servo3_target = 90;
byte Servo4_target = 90;
byte Servo5_target = 90;
byte Servo6_target = 90;
unsigned long currentMillis = millis();

bool invert_servo1 = false;
bool invert_servo2 = false;
bool invert_servo3 = false;
bool invert_servo4 = false;
bool invert_servo5 = false;
bool invert_servo6 = false;

word failSaveServo1 = 90; //failsave position 0-180
word failSaveServo2 = 90;
word failSaveServo3 = 90;
word failSaveServo4 = 90;
word failSaveServo5 = 90;
word failSaveServo6 = 90;

word maxRangeServo1 = 0;
word maxRangeServo2 = 0;
word maxRangeServo3 = 0;
word maxRangeServo4 = 0;
word maxRangeServo5 = 0;
word maxRangeServo6 = 0;

word minRangeServo1 = 0;
word minRangeServo2 = 0;
word minRangeServo3 = 0;
word minRangeServo4 = 0;
word minRangeServo5 = 0;
word minRangeServo6 = 0;

short TrimServo1 = 0;
short TrimServo2 = 0;
short TrimServo3 = 0;
short TrimServo4 = 0;
short TrimServo5 = 0;
short TrimServo6 = 0;

byte ExpoServo1 = 0;
byte ExpoServo2 = 0;
byte ExpoServo3 = 0;
byte ExpoServo4 = 0;
byte ExpoServo5 = 0;
byte ExpoServo6 = 0;


byte RateServo1 = 0;
byte RateServo2 = 0;
byte RateServo3 = 0;
byte RateServo4 = 0;
byte RateServo5 = 0;
byte RateServo6 = 0;


//float expor=0.20;
double CalcExpoServo1 = 0; //=pow(4,expor);
double CalcExpoServo2 = 0;
double CalcExpoServo3 = 0;
double CalcExpoServo4 = 0;
double CalcExpoServo5 = 0;
double CalcExpoServo6 = 0;


byte RCmode = 0;
byte FailSaveTime = 5;

char  RCname[64] = "";
char  RCSSID[64] = "SSID";//WiFi.macAddress().ToString()+" (miharix.eu)";
char  RCPASS[64] = "miharix.eu";
//char  RCSSID[64] = "S55MX 2,4Ghz"; //WiFi.macAddress()+" (miharix.eu)";
//char  RCPASS[64] = "mihamiha";
bool WiFiAP = true; //make WiFi AP 1 or connect to wifi 0
bool factory_boot = false;

bool ResetToFactoryFlag = false;

String getContentType(String filename); // convert the file extension to the MIME type
bool handleFileRead(String path);       // send the right file to the client (if it exists)

void setup() {
  pinMode(HARD_RESET_PIN, INPUT);
#ifdef DEBUG1
  Serial.begin(9600);         // Start the Serial communication to send messages to the computer
  delay(10);
  Serial.println('\n');
#endif
  SPIFFS.begin();                           // Start the SPI Flash Files System
  loadConfig();
  delay(10);
  // WiFi.disconnect();  //erese old ssid password

  if (!WiFiAP) { //Connect to wifi
    WiFi.begin(RCSSID, RCPASS);
#ifdef DEBUG1
    Serial.print("Connecting to ");
    Serial.print(RCSSID); Serial.println(" ...");
#endif
    int NC_count = 0;
    while (WiFi.status() != WL_CONNECTED) { // Wait for the Wi-Fi to connect
      delay(1000);
#ifdef DEBUG1
      Serial.print('.');
#endif
      if (NC_count > 300) {
        ResetToFactoryFlag = true;
        ResetToFactory();
      }
      NC_count++;

    }
#ifdef DEBUG1
    Serial.println('\n');
    Serial.print("Connected to ");
    Serial.println(WiFi.SSID());              // Tell us what network we're connected to
    Serial.print("IP address:\t");
    Serial.println(WiFi.localIP());           // Send the IP address of the ESP8266 to the computer
#endif
  } else { //go AP wifi mode
    WiFi.softAP(RCSSID, RCPASS);             // Start the access point
#ifdef DEBUG1
    Serial.print(RCSSID);
    Serial.print("Access Point \"");
    Serial.println("\" started");
    Serial.print("IP address:\t");
    Serial.println(WiFi.softAPIP());         // Send the IP address of the ESP8266 to the computer
#endif

  }

  /* wifiMulti.addAP("S55MX 2,4Ghz", "mihamiha");   // add Wi-Fi networks you want to connect to
    wifiMulti.addAP("ssid_from_AP_2", "your_password_for_AP_2");
    wifiMulti.addAP("ssid_from_AP_3", "your_password_for_AP_3");*/

  // Serial.println("Connecting ...");
  // int i = 0;
  /* while (wifiMulti.run() != WL_CONNECTED) { // Wait for the Wi-Fi to connect
     delay(250);
     Serial.print('.');
    }*/


  if (MDNS.begin("rc")) {              // Start the mDNS responder for rc.local
#ifdef DEBUG1
    Serial.println("mDNS responder started");
  } else {
    Serial.println("Error setting up MDNS responder!");
#endif
  }


  // server.on("/setup.html", HTTP_GET, get_response);


  server.onNotFound([]() {                              // If the client requests any URI
    if (!handleFileRead(server.uri()))                  // send it if it exists
      server.send(404, "text/plain", "404: Not Found"); // otherwise, respond with a 404 (Not Found) error
  });

  server.begin();                           // Actually start the server
#ifdef DEBUG
  Serial.println("HTTP server started");
#endif
  webSocket.begin();
  webSocket.onEvent(webSocketEvent);
#ifdef DEBUG
  Serial.println("websocket server started");
#endif
  servos_attach();
  CalcExpoRates();

  pinMode(2, OUTPUT);
  for (uint8_t t = 4; t > 0; t--) { //blink on boot
    digitalWrite(2, HIGH);
    delay(50);
    digitalWrite(2, LOW);
    delay(50);
  }

  // Add service to MDNS
  MDNS.addService("http", "tcp", 80);
  MDNS.addService("ws", "tcp", 81);
}

void servos_attach() {
  //set servo init value <<<<<<<<<<<<<<<<--------------------------------------
  servo1.attach(SERVO1, minRangeServo1, maxRangeServo1);
  servo1.writeMicroseconds(failSaveServo1);
  servo2.attach(SERVO2, minRangeServo2, maxRangeServo2);
  servo2.writeMicroseconds(failSaveServo2);
  servo3.attach(SERVO3, minRangeServo3, maxRangeServo3);
  servo3.writeMicroseconds(failSaveServo3);
  servo4.attach(SERVO4, minRangeServo4, maxRangeServo4);
  servo4.writeMicroseconds(failSaveServo4);
  servo5.attach(SERVO5, minRangeServo5, maxRangeServo5);
  servo5.writeMicroseconds(failSaveServo5);
  servo6.attach(SERVO6, minRangeServo6, maxRangeServo6);
  servo6.writeMicroseconds(failSaveServo6);
}
void servos_dettach() {
  servo1.detach();
  servo2.detach();
  servo3.detach();
  servo4.detach();
  servo5.detach();
  servo6.detach();
}

void CalcExpoRates() {
#ifdef DEBUG1
  Serial.println("ExpoServo1");
  Serial.println(ExpoServo1);
#endif
  float tempR = 2;
  tempR = ExpoServo1 / 100.0;
#ifdef DEBUG1
  Serial.println("tempR");
  Serial.println(tempR);
#endif
  CalcExpoServo1 = pow(4, tempR);
#ifdef DEBUG1
  Serial.println("CalcExpoServo1");
  Serial.println(CalcExpoServo1);

  Serial.println("ExpoServo2");
  Serial.println(ExpoServo2);
#endif
  tempR = ExpoServo2 / 100.0;
#ifdef DEBUG1
  Serial.println("tempR2");
  Serial.println(tempR);
#endif
  CalcExpoServo2 = pow(4, tempR);
#ifdef DEBUG1
  Serial.println("CalcExpoServo2");
  Serial.println(CalcExpoServo2);
#endif
  tempR = ExpoServo3 / 100.0;
  CalcExpoServo3 = pow(4, tempR);

  tempR = ExpoServo4 / 100.0;
  CalcExpoServo4 = pow(4, tempR);

  tempR = ExpoServo5 / 100.0;
  CalcExpoServo5 = pow(4, tempR);

    tempR = ExpoServo6 / 100.0;
  CalcExpoServo6 = pow(4, tempR);

}


int exponentRC(float input, double calcrate, int servotrim) {
  if (input > 180) {
    input = 180;
  }
  if (input < 0) {
    input = 0;
  }
  input = input - 90;
  input = input / 100;

  if (input > 0) {
    input = (100 * pow(input, calcrate) + 90) + servotrim;
    if (input > 180) {
      return 180;
    }
    return input;
  }

  if (input < 0) {
    input = (100 * - pow(-input, calcrate) + 90) + servotrim;
    if (input < 0) {
      return 0;
    }
    return input;
  }

  return 90 + servotrim;
}

void webSocketEvent(uint8_t num, WStype_t type, uint8_t * payload, size_t length) {

  switch (type) {
    case WStype_DISCONNECTED:

#ifdef DEBUG
      Serial.printf("[%u] Disconnected!\n", num);
#endif

      digitalWrite(2, LOW);

      break;
    case WStype_CONNECTED: {
        IPAddress ip = webSocket.remoteIP(num);

#ifdef DEBUG
        Serial.printf("[%u] Connected from %d.%d.%d.%d url: %s\n", num, ip[0], ip[1], ip[2], ip[3], payload);
#endif

        // send message to client
        webSocket.sendTXT(num, "Connected");
      }
      break;
    case WStype_TEXT:

#ifdef DEBUG
      Serial.printf("[%u] get Text: %s\n", num, payload);
#endif

      if ((payload[0] == 'S') && (payload[13] == '\n')) {

        memcpy(S1_buff, &payload[1], 2 );
        // S1_buff[3] = '\0';


        memcpy(S2_buff, &payload[3], 2 );
        //     S2_buff[3] = '\0';

        memcpy(S3_buff, &payload[5], 2 );
        //   S3_buff[3] = '\0';

        memcpy(S4_buff, &payload[7], 2 );
        //  S4_buff[3] = '\0';

        memcpy(S5_buff, &payload[9], 2 );
        //S5_buff[3] = '\0';

        memcpy(S6_buff, &payload[11], 2 );
        //S6_buff[3] = '\0';

        S1_6_flag = true;

        if (S1_buff[0] == '-') { //prevent buffer owerflow
          S1_buff[0] = '0';
          S1_buff[1] = '0';
        }
        if (S2_buff[0] == '-') {
          S2_buff[0] = '0';
          S2_buff[1] = '0';
        }
        if (S3_buff[0] == '-') {
          S3_buff[0] = '0';
          S3_buff[1] = '0';
        }
        if (S4_buff[0] == '-') {
          S4_buff[0] = '0';
          S4_buff[1] = '0';
        }
        if (S5_buff[0] == '-') {
          S5_buff[0] = '0';
          S5_buff[1] = '0';
        }
        if (S6_buff[0] == '-') {
          S6_buff[0] = '0';
          S6_buff[1] = '0';
        }

#ifdef DEBUG
        Serial.printf(" S1_6_flag=%d", S1_6_flag);
        Serial.printf("\nS1_buff=%u", strtol(S1_buff, NULL, 16));
        Serial.printf("\nS1_buff+trim1=%d", TrimServo1);
        Serial.printf("\nS1_buff+trim1=%u", strtol(S1_buff, NULL, 16) + TrimServo1);

        Serial.printf("\nS2_buff=%u", strtol(S2_buff, NULL, 16));
        Serial.printf("\nS3_buff=%u", strtol(S3_buff, NULL, 16));
        Serial.printf("\nS4_buff=%u", strtol(S4_buff, NULL, 16));
        Serial.printf("\nS5_buff=%u", strtol(S5_buff, NULL, 16));
        Serial.printf("\nS6_buff=%u", strtol(S6_buff, NULL, 16));
#endif


        if (invert_servo1) {
          //servo1.write(180 - (strtol(S1_buff, NULL, 16)) + TrimServo1);
          Servo1_target = 180 - strtol(S1_buff, NULL, 16);
        } else {
          //servo1.write(strtol(S1_buff, NULL, 16) + TrimServo1);
          Servo1_target = strtol(S1_buff, NULL, 16);
        }
        Servo1_target = exponentRC(Servo1_target, CalcExpoServo1, TrimServo1);

        if (invert_servo2) {
          Servo2_target = 180 - strtol(S2_buff, NULL, 16);
          //servo2.write(180 - (strtol(S2_buff, NULL, 16)) + TrimServo2);
        } else {
          Servo2_target = strtol(S2_buff, NULL, 16);
          //servo2.write(strtol(S2_buff, NULL, 16) + TrimServo2);
        }
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
void loop(void) {

  ResetToFactory();
  webSocket.loop();

  currentMillis = millis();
  if (currentMillis - previousMillis >= interval) {
#ifdef DEBUG
    Serial.printf("S1_6_flag=%d\n", S1_6_flag);
#endif
    previousMillis = currentMillis;
    if (S1_6_flag == false) {
      SameStateCount++;
      if (SameStateCount >= FailSaveTime) {
        servo1.write(failSaveServo1);
        servo2.write(failSaveServo2);
        servo3.write(failSaveServo3);
        servo4.write(failSaveServo4);
        servo5.write(failSaveServo5);
        servo6.write(failSaveServo6);
        digitalWrite(2, LOW);
      }
    } else {
      digitalWrite(2, HIGH);
      SameStateCount = 0;
      S1_6_flag = false;
    }
  }

  if (SameStateCount < FailSaveTime) {
    servo_go();
  }


  server.handleClient();
}

void print_variables() {
  PRINTLN(invert_servo1);
  PRINTLN(invert_servo2);
  PRINTLN(invert_servo3);
  PRINTLN(invert_servo4);
  PRINTLN(invert_servo5);
  PRINTLN(invert_servo6);

  PRINTLN(failSaveServo1);
  PRINTLN(failSaveServo2);
  PRINTLN(failSaveServo3);
  PRINTLN(failSaveServo4);
  PRINTLN(failSaveServo5);
  PRINTLN(failSaveServo6);

  PRINTLN(maxRangeServo1);
  PRINTLN(maxRangeServo2);
  PRINTLN(maxRangeServo3);
  PRINTLN(maxRangeServo4);
  PRINTLN(maxRangeServo5);
  PRINTLN(maxRangeServo6);

  PRINTLN(minRangeServo1);
  PRINTLN(minRangeServo2);
  PRINTLN(minRangeServo3);
  PRINTLN(minRangeServo4);
  PRINTLN(minRangeServo5);
  PRINTLN(minRangeServo6);

  PRINTLN(ExpoServo1);
  PRINTLN(ExpoServo2);
  PRINTLN(ExpoServo3);
  PRINTLN(ExpoServo4);
  PRINTLN(ExpoServo5);
  PRINTLN(ExpoServo6);

  PRINTLN(TrimServo1);
  PRINTLN(TrimServo2);
  PRINTLN(TrimServo3);
  PRINTLN(TrimServo4);
  PRINTLN(TrimServo5);
  PRINTLN(TrimServo6);

  PRINTLN(RateServo1);
  PRINTLN(RateServo2);
  PRINTLN(RateServo3);
  PRINTLN(RateServo4);
  PRINTLN(RateServo5);
  PRINTLN(RateServo6);

  PRINTLN(RCmode);
  PRINTLN(FailSaveTime);
  PRINTLN(RCname);
  PRINTLN(RCSSID);
  PRINTLN(RCPASS);
  PRINTLN(WiFiAP);
}


String getContentType(String filename) { // convert the file extension to the MIME type

  if (filename.endsWith(".htm")) return "text/html";
  else if (filename.endsWith(".html")) return "text/html";
  else if (filename.endsWith(".css")) return "text/css";
  else if (filename.endsWith(".js")) return "application/javascript";
  else if (filename.endsWith(".json")) return "application/json";
  else if (filename.endsWith(".png")) return "image/png";
  else if (filename.endsWith(".gif")) return "image/gif";
  else if (filename.endsWith(".jpg")) return "image/jpeg";
  else if (filename.endsWith(".svg")) return "image/svg+xml";
  else if (filename.endsWith(".ico")) return "image/x-icon";
  else if (filename.endsWith(".xml")) return "text/xml";
  else if (filename.endsWith(".pdf")) return "application/x-pdf";
  else if (filename.endsWith(".zip")) return "application/x-zip";
  else if (filename.endsWith(".gz")) return "application/x-gzip";
  return "text/html";
}

bool saveConfig() {
  print_variables();
  File configFile = SPIFFS.open("/config.json", "w");
  if (!configFile) {
    return false;
  }
  StaticJsonBuffer<1124> jsonBuffer;
  JsonObject &json = jsonBuffer.createObject();

  if (!factory_boot) {
    json["SSID"] = RCSSID;
  } else {
    json["SSID"] = "SSID";
  }
  json["Pass"] = RCPASS;
  json["WiFiAP"] = WiFiAP;
  json["RCname"] = RCname;
  json["Mode"] = RCmode;
  json["Ftime"] = FailSaveTime;

  JsonObject& Servo1 = json.createNestedObject("Servo1");
  JsonObject& Servo2 = json.createNestedObject("Servo2");
  JsonObject& Servo3 = json.createNestedObject("Servo3");
  JsonObject& Servo4 = json.createNestedObject("Servo4");
  JsonObject& Servo5 = json.createNestedObject("Servo5");
  JsonObject& Servo6 = json.createNestedObject("Servo6");

  Servo1["max"] = maxRangeServo1;
  Servo2["max"] = maxRangeServo2;
  Servo3["max"] = maxRangeServo3;
  Servo4["max"] = maxRangeServo4;
  Servo5["max"] = maxRangeServo5;
  Servo6["max"] = maxRangeServo6;

  Servo1["min"] = minRangeServo1;
  Servo2["min"] = minRangeServo2;
  Servo3["min"] = minRangeServo3;
  Servo4["min"] = minRangeServo4;
  Servo5["min"] = minRangeServo5;
  Servo6["min"] = minRangeServo6;

  Servo1["trim"] = TrimServo1;
  Servo2["trim"] = TrimServo2;
  Servo3["trim"] = TrimServo3;
  Servo4["trim"] = TrimServo4;
  Servo5["trim"] = TrimServo5;
  Servo6["trim"] = TrimServo6;

  Servo1["failsave"] = failSaveServo1;
  Servo2["failsave"] = failSaveServo2;
  Servo3["failsave"] = failSaveServo3;
  Servo4["failsave"] = failSaveServo4;
  Servo5["failsave"] = failSaveServo5;
  Servo6["failsave"] = failSaveServo6;

  Servo1["expo"] = ExpoServo1;
  Servo2["expo"] = ExpoServo2;
  Servo3["expo"] = ExpoServo3;
  Servo4["expo"] = ExpoServo4;
  Servo5["expo"] = ExpoServo5;
  Servo6["expo"] = ExpoServo6;

  Servo1["rate"] = RateServo1;
  Servo2["rate"] = RateServo2;
  Servo3["rate"] = RateServo3;
  Servo4["rate"] = RateServo4;
  Servo5["rate"] = RateServo5;
  Servo6["rate"] = RateServo6;

  Servo1["reverse"] = invert_servo1;
  Servo2["reverse"] = invert_servo2;
  Servo3["reverse"] = invert_servo3;
  Servo4["reverse"] = invert_servo4;
  Servo5["reverse"] = invert_servo5;
  Servo6["reverse"] = invert_servo6;

  if (json.prettyPrintTo(configFile) == 0) {
#ifdef DEBUG1
    Serial.println(F("Failed to write to file"));
#endif
  }

  // Close the file (File's destructor doesn't close the file)
  configFile.close();
  return true;
}

bool loadConfig() {
    
  File configFile = SPIFFS.open("/config.json", "r"); 
  if (!configFile) {
    return false;
  }
   
  size_t size = configFile.size();

#ifdef DEBUG1
  Serial.println(size);
#endif
  if (size > 1124) {
#ifdef DEBUG1
    Serial.println("Config to big");
#endif


    return false;
  }
        
  std::unique_ptr<char[]> buf(new char[size]);
  configFile.readBytes(buf.get(), size);
#ifdef DEBUG
  Serial.println(buf.get());
#endif
  StaticJsonBuffer<1124> jsonBuffer;
  JsonObject& json = jsonBuffer.parseObject(buf.get());
  if (!json.success()) {
#ifdef DEBUG1
    Serial.println("parser error");
#endif
   return false;
  }
  configFile.close();//close the file

  invert_servo1 = json["Servo1"]["reverse"];
  invert_servo2 = json["Servo2"]["reverse"];
  invert_servo3 = json["Servo3"]["reverse"];
  invert_servo4 = json["Servo4"]["reverse"];
  invert_servo5 = json["Servo5"]["reverse"];
  invert_servo6 = json["Servo6"]["reverse"];

  failSaveServo1 = json["Servo1"]["failsave"];
  failSaveServo2 = json["Servo2"]["failsave"];
  failSaveServo3 = json["Servo3"]["failsave"];
  failSaveServo4 = json["Servo4"]["failsave"];
  failSaveServo5 = json["Servo5"]["failsave"];
  failSaveServo6 = json["Servo6"]["failsave"];

  maxRangeServo1 = json["Servo1"]["max"];
  maxRangeServo2 = json["Servo2"]["max"];
  maxRangeServo3 = json["Servo3"]["max"];
  maxRangeServo4 = json["Servo4"]["max"];
  maxRangeServo5 = json["Servo5"]["max"];
  maxRangeServo6 = json["Servo6"]["max"];

  minRangeServo1 = json["Servo1"]["min"];
  minRangeServo2 = json["Servo2"]["min"];
  minRangeServo3 = json["Servo3"]["min"];
  minRangeServo4 = json["Servo4"]["min"];
  minRangeServo5 = json["Servo5"]["min"];
  minRangeServo6 = json["Servo6"]["min"];

  TrimServo1 = json["Servo1"]["trim"];
  TrimServo2 = json["Servo2"]["trim"];
  TrimServo3 = json["Servo3"]["trim"];
  TrimServo4 = json["Servo4"]["trim"];
  TrimServo5 = json["Servo5"]["trim"];
  TrimServo6 = json["Servo6"]["trim"];

  ExpoServo1 = json["Servo1"]["expo"];
  ExpoServo2 = json["Servo2"]["expo"];
  ExpoServo3 = json["Servo3"]["expo"];
  ExpoServo4 = json["Servo4"]["expo"];
  ExpoServo5 = json["Servo5"]["expo"];
  ExpoServo6 = json["Servo6"]["expo"];

  RateServo1 = json["Servo1"]["rate"];
  RateServo2 = json["Servo2"]["rate"];
  RateServo3 = json["Servo3"]["rate"];
  RateServo4 = json["Servo4"]["rate"];
  RateServo5 = json["Servo5"]["rate"];
  RateServo6 = json["Servo6"]["rate"];

  RCmode = json["Mode"];
  FailSaveTime = json["Ftime"];

  strlcpy(RCname, json["RCname"], sizeof(RCname));
#ifdef DEBUG1
  Serial.println(RCSSID);
#endif
  if (json["SSID"] != "SSID") {
    strlcpy(RCSSID, json["SSID"], sizeof(RCSSID));
    strlcpy(RCPASS, json["Pass"], sizeof(RCPASS));
    WiFiAP = json["WiFiAP"];
  } else {//ssid not set go AP use mac and display pass
    unsigned char masrc[6];
    WiFi.macAddress(masrc);
    String macRC = String(masrc[0], 16) + ":" + String(masrc[1], 16) + ":" + String(masrc[2], 16) + ":" + String(masrc[3], 16) + ":" + String(masrc[4], 16) + ":" + String(masrc[5], 16) + " (miharix.eu)";
#ifdef DEBUG1
    Serial.println(macRC);
#endif
    macRC.toCharArray(RCSSID, sizeof(RCSSID));
    strlcpy(RCPASS, "miharix.eu", sizeof(RCPASS));
    WiFiAP = true;
    factory_boot = true; //first time boot -> on root go to FAQ.html
  }


  print_variables();
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

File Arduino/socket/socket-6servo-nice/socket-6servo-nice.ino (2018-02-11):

#include <Arduino.h>

#include <ESP8266WiFi.h>
#include <ESP8266WiFiMulti.h>
#include <ESP8266WebServer.h>
#include <WebSocketsServer.h>
#include <ESP8266mDNS.h>
#include <Hash.h>
#include <Servo.h>

//#define DEBUG

//adjust this <<<<<<<<<<--------------
#define SERVO1   4
#define SERVO2   5
#define SERVO3   16
#define SERVO4   14
#define SERVO5   13
#define SERVO6   12

const bool invert_servo1 = true;
const bool invert_servo2 = false;
const bool invert_servo3 = false;
const bool invert_servo4 = false;
const bool invert_servo5 = false;
const bool invert_servo6 = false;

const char *ssid = "miharix_WiFi_RC";
const char *password = "mihamiha";

uint32_t failsaveS=5; //seconds whithout new input till failsave
const uint8_t failSaveServo1 = 90; //failsave position 0-180
const uint8_t failSaveServo2 = 90;
const uint8_t failSaveServo3 = 90;
const uint8_t failSaveServo4 = 90;
const uint8_t failSaveServo5 = 90;
const uint8_t failSaveServo6 = 90;

const uint8_t initSaveServo1 = 90; //startup servo position 0-180
const uint8_t initSaveServo2 = 90;
const uint8_t initSaveServo3 = 90;
const uint8_t initSaveServo4 = 90;
const uint8_t initSaveServo5 = 90;
const uint8_t initSaveServo6 = 90;
//end of adjusting, more is at the botom



#ifdef DEBUG
#define USE_SERIAL Serial
#endif
const long interval = 1000;
int same=0;


//nipples https://github.com/yoannmoinet/nipplejs

const char skripta[] PROGMEM = "<!DOCTYPE html>"
"<html><head><meta charset='UTF-8'><meta name='viewport' content='width=device-width, initial-scale=1, maximum-scale=1, user-scalable=0'/>"
"<title>Miharix WiFi RC</title>"
"<script>"    
    "var Servo1=0;"
    "var Servo2=0;"
    "var Servo3=0;"
    "var Servo4=0;"
    "var Servo5=0;"
    "var Servo6=0;"
    "var connection = new WebSocket('ws://'+location.hostname+':81/', ['arduino']);"
    "connection.onopen = function () {"
     "connection.send('Connect ' + new Date());"
    "};"
    "connection.onerror = function (error) {"
      "console.log('WebSocket Error ', error);"
    "};"
    "connection.onmessage = function (e) {"
      "console.log('Server: ', e.data);"
    "};"
    "function sendServo(){"
      "S1 =parseInt(Servo1).toString(16);"
      "S2 =parseInt(Servo2).toString(16);"
      "S3 =parseInt(Servo3).toString(16);"
      "S4 =parseInt(Servo4).toString(16);"
      "var S5 = parseInt(document.getElementById('S5').value).toString(16);"
      "var S6 = parseInt(document.getElementById('S6').value).toString(16);"
      "if(S1.length < 2) { S1 = '0' + S1; }"
      "if(S2.length < 2) { S2 = '0' + S2; }"
      "if(S3.length < 2) { S3 = '0' + S3; }"
      "if(S4.length < 2) { S4 = '0' + S4; }"
      "if(S5.length < 2) { S5 = '0' + S5; }"
      "if(S6.length < 2) { S6 = '0' + S6; }"
      "var S1_6 = S1+S2+S3+S4+S5+S6;"
      "console.log('S1_6: ' + S1_6);"
      "connection.send('S'+S1_6+'\\n');"
     "}"
     "</script>"
     
     
     "<script charset='utf-8'>!function(t){if(\"object\"==typeof exports&&\"undefined\"!=typeof module)module.exports=t();else if(\"function\"==typeof define&&define.amd)define([],t);else{var e;e=\"undefined\"!=typeof window?window:\"undefined\"!=typeof global?global:\"undefined\"!=typeof self?self:this,e.nipplejs=t()}}(function(){function t(){}function e(t,i){return this.identifier=i.identifier,this.position=i.position,this.frontPosition=i.frontPosition,this.collection=t,this.defaults={size:100,threshold:.1,color:\"white\",fadeTime:250,dataOnly:!1,restOpacity:.5,mode:\"dynamic\",zone:document.body},this.config(i),\"dynamic\"===this.options.mode&&(this.options.restOpacity=0),this.id=e.id,e.id+=1,this.buildEl().stylize(),this.instance={el:this.ui.el,on:this.on.bind(this),off:this.off.bind(this),show:this.show.bind(this),hide:this.hide.bind(this),add:this.addToDom.bind(this),remove:this.removeFromDom.bind(this),destroy:this.destroy.bind(this),resetDirection:this.resetDirection.bind(this),computeDirection:this.computeDirection.bind(this),trigger:this.trigger.bind(this),position:this.position,frontPosition:this.frontPosition,ui:this.ui,identifier:this.identifier,id:this.id,options:this.options},this.instance}function i(t,e){var n=this;return n.nipples=[],n.idles=[],n.actives=[],n.ids=[],n.pressureIntervals={},n.manager=t,n.id=i.id,i.id+=1,n.defaults={zone:document.body,multitouch:!1,maxNumberOfNipples:10,mode:\"dynamic\",position:{top:0,left:0},catchDistance:200,size:100,threshold:.1,color:\"white\",fadeTime:250,dataOnly:!1,restOpacity:.5},n.config(e),\"static\"!==n.options.mode&&\"semi\"!==n.options.mode||(n.options.multitouch=!1),n.options.multitouch||(n.options.maxNumberOfNipples=1),n.updateBox(),n.prepareNipples(),n.bindings(),n.begin(),n.nipples}function n(t){var e=this;e.ids={},e.index=0,e.collections=[],e.config(t),e.prepareCollections();var i;return c.bindEvt(window,\"resize\",function(t){clearTimeout(i),i=setTimeout(function(){var t,i=c.getScroll();e.collections.forEach(function(e){e.forEach(function(e){t=e.el.getBoundingClientRect(),e.position={x:i.x+t.left,y:i.y+t.top}})})},100)}),e.collections}var o,r=!!(\"ontouchstart\"in window),s=!!window.PointerEvent,d=!!window.MSPointerEvent,a={touch:{start:\"touchstart\",move:\"touchmove\",end:\"touchend\"},mouse:{start:\"mousedown\",move:\"mousemove\",end:\"mouseup\"},pointer:{start:\"pointerdown\",move:\"pointermove\",end:\"pointerup\"},MSPointer:{start:\"MSPointerDown\",move:\"MSPointerMove\",end:\"MSPointerUp\"}},p={};s?o=a.pointer:d?o=a.MSPointer:r?(o=a.touch,p=a.mouse):o=a.mouse;var c={};c.distance=function(t,e){var i=e.x-t.x,n=e.y-t.y;return Math.sqrt(i*i+n*n)},c.angle=function(t,e){var i=e.x-t.x,n=e.y-t.y;return c.degrees(Math.atan2(n,i))},c.findCoord=function(t,e,i){var n={x:0,y:0};return i=c.radians(i),n.x=t.x-e*Math.cos(i),n.y=t.y-e*Math.sin(i),n},c.radians=function(t){return t*(Math.PI/180)},c.degrees=function(t){return t*(180/Math.PI)},c.bindEvt=function(t,e,i){t.addEventListener?t.addEventListener(e,i,!1):t.attachEvent&&t.attachEvent(e,i)},c.unbindEvt=function(t,e,i){t.removeEventListener?t.removeEventListener(e,i):t.detachEvent&&t.detachEvent(e,i)},c.trigger=function(t,e,i){var n=new CustomEvent(e,i);t.dispatchEvent(n)},c.prepareEvent=function(t){return t.preventDefault(),t.type.match(/^touch/)?t.changedTouches:t},c.getScroll=function(){var t=void 0!==window.pageXOffset?window.pageXOffset:(document.documentElement||document.body.parentNode||document.body).scrollLeft,e=void 0!==window.pageYOffset?window.pageYOffset:(document.documentElement||document.body.parentNode||document.body).scrollTop;return{x:t,y:e}},c.applyPosition=function(t,e){e.x&&e.y?(t.style.left=e.x+\"px\",t.style.top=e.y+\"px\"):(e.top||e.right||e.bottom||e.left)&&(t.style.top=e.top,t.style.right=e.right,t.style.bottom=e.bottom,t.style.left=e.left)},c.getTransitionStyle=function(t,e,i){var n=c.configStylePropertyObject(t);for(var o in n)if(n.hasOwnProperty(o))if(\"string\"==typeof e)n[o]=e+\" \"+i;else{for(var r=\"\",s=0,d=e.length;s<d;s+=1)r+=e[s]+\" \"+i+\", \";n[o]=r.slice(0,-2)}return
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

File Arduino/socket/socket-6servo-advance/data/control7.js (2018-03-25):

   var Servo1=0;
    var Servo2=0;
    var Servo3=0;
    var Servo4=0;
    var Servo5=0;
    var Servo6=0;
    
    var connection = new WebSocket('ws://'+location.hostname+':81/', ['arduino']);
    connection.onopen = function () {
   //   connection.send('Connect ' + new Date()); 
    };
    connection.onerror = function (error) {
      console.log('WebSocket Error ', error);
    };
    connection.onmessage = function (e) {
      console.log('Server: ', e.data);
    };

    function sendServo2(){
	var S3 = "0";
	var S4 = "0";    
	var S5 = "0";
	var S6 = "0";

	Servo1=Servo1/90-1
	Servo2=Servo2/90-1
//https://electronics.stackexchange.com/questions/19669/algorithm-for-mixing-2-axis-analog-input-to-control-a-differential-motor-drive
	//convert to polar   
    	r = Math.hypot(Servo2, Servo1)
	t = Math.atan2(Servo1, Servo2)
	
	//rotate by 45 degrees
	t += Math.PI / 4
	//back to cartesian
	Servo1 = r * Math.cos(t)
	Servo2 = r * Math.sin(t)
	//rescale the new coords
	Servo1 = Servo1 * Math.sqrt(2)
	Servo2 = Servo2 * Math.sqrt(2)
	//clamp to -1/+1
	Servo1 = Math.max(-1, Math.min(Servo1, 1))
	Servo2 = Math.max(-1, Math.min(Servo2, 1))

	Servo1=(Servo1+1)*90
	Servo2=(Servo2+1)*90

	S2 =parseInt(Servo1).toString(16);
      	S1 =parseInt(Servo2).toString(16);

	if(S1.length < 2) { S1 = '0' + S1; }
        if(S2.length < 2) { S2 = '0' + S2; }
	if(S3.length < 2) { S3 = '0' + S3; }
	if(S4.length < 2) { S4 = '0' + S4; }
	if(S5.length < 2) { S5 = '0' + S5; }
	if(S6.length < 2) { S6 = '0' + S6; }
	//console.clear();
	//console.log('S1: ' + S1+' S2: ' + S2);
	//console.log('Servo1: ' + Servo1+' Servo2: ' + Servo2);
        
	var S1_6 = S1+S2+S3+S4+S5+S6;
        //console.log('S1_6: ' + S1_6);
        connection.send('S'+S1_6+'\n');

    }

    function sendServo(){
      S1 =parseInt(Servo1).toString(16);
      S2 =parseInt(Servo2).toString(16);
      var S3 = "0";
      var S4 = "0";    
      var S5 = "0";
      var S6 = "0";
      
      if(S1.length < 2) { S1 = '0' + S1; }
      if(S2.length < 2) { S2 = '0' + S2; }
      if(S3.length < 2) { S3 = '0' + S3; }
      if(S4.length < 2) { S4 = '0' + S4; }
      if(S5.length < 2) { S5 = '0' + S5; }
      if(S6.length < 2) { S6 = '0' + S6; }
	//console.clear();
	//console.log('O1: ' + O1+' O2: ' + O2);
      //console.log('Servo1: ' + Servo1+' Servo2: ' + Servo2);
      var S1_6 = S1+S2+S3+S4+S5+S6;

     // console.log('S1_6: ' + S1_6);
      connection.send('S'+S1_6+'\n');
     }

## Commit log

2017-07-01 Krmiljenje 2 servota HTTP in Socket nacin Datoteke za ZOTKS tabor2017
2017-07-14 Files for making the PCB
2017-08-21 3Dp case, interesing links, 6servo example
    [pcb_protect.scad, pcb_protect.stl]
2017-08-23 6 servo demo
2018-02-11 Prevent selecting text tool
    [socket-2servo-nice.ino]
2019-03-17 added control14
    [pcb_protect_v3.stl]
2019-06-30 New interface & corrected arduino dependency list
    [socket-6servo-advance.ino]
2019-11-24 Fixed SSID / password - max lengt bug
    [socket-6servo-advance.ino]
2019-11-24 Some models that kids have build in class and than controled using this module.
    [nacrt.dxf, sumpi.dxf, sumpi.scad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]

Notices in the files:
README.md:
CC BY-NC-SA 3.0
